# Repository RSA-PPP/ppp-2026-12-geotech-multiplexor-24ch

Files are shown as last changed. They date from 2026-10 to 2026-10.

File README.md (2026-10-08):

# ppp-2026-13-geotech-multiplexor-24ch

> **Red Sísmica del Austro (RSA) — Universidad de Cuenca**  
> Prácticas Preprofesionales (PPP) • Sistemas Embebidos, Instrumentación Geotécnica y Control Electromecánico

---

## 📋 Ficha Técnica del Proyecto

| Campo | Detalle |
| :--- | :--- |
| **Código Institucional** | `RSA-PPP-2026-13` |
| **Nombre del Proyecto** | Sistema de Adquisición Electromecánico Multiplexado para Galgas Extensométricas en Presas (ESP32 y PIC16F628A) |
| **Pasante** | Walter Calderón (`walter.calderon@ucuenca.edu.ec`) |
| **Carrera / Institución** | Ingeniería en Telecomunicaciones — Universidad de Cuenca |
| **Tutor Institucional** | Ing. Milton Muñoz (`milton.munozc@ucuenca.edu.ec`) — RSA |
| **Duración / Horas** | 144 horas (10.5 semanas) • Presencial |
| **Fecha de Ejecución** | 2026-10-01 al 2026-12-18 |
| **Estado** | `En Ejecución` |

---

## 🎯 Descripción General y Objetivos

La Red Sísmica del Austro (RSA) gestiona la auscultación estructural continua de presas hidroeléctricas críticas (como Chanlud y Labrado), donde la monitorización de la estabilidad del cuerpo de presa depende de redes de **galgas extensométricas de 4 hilos** embebidas en el concreto y galerías. Cada sensor entrega dos variables físicas acopladas: **deformación mecánica ($\mu\varepsilon$)** y **temperatura interna ($^\circ\text{C}$)** para compensación térmica.

Para optimizar costos de instrumental analógico de ultra alta resolución, el sistema utiliza un mecanismo de multiplexación electromecánica compuesto por **dos selectores rotativos mecánicos de 12 canales** (totalizando 24 sensores analógicos). Cada selector es gobernado por un motor DC acoplado a encoders ópticos de ranura y referencia absoluta (*Home*). La conmutación entre el modo de deformación y el modo de temperatura se realiza mediante un banco de relés (K1..K5) que reconfigura un puente de Wheatstone conectado al convertidor analógico-digital de 24 bits **HX711**.

Este proyecto implementa una arquitectura distribuida de firmware resiliente y de alta precisión:
* **Controlador Esclavo (Microchip PIC16F628A):** Firmware en C (XC8) para posicionamiento angular determinista por interrupciones, frenado dinámico activo en puente H L293D y parser binario UART a 9600 bps.
* **Nodo Maestro de Gestión (Espressif ESP32-WROOM-32):** Firmware en C++ (PlatformIO) para lectura del HX711, secuenciamiento de relés con tiempos muertos de guarda ($\ge 20\text{ ms}$), datalogger autónomo en MicroSD (FAT32/CSV), pantalla LCD alfanumérica y telemetría por comandos ASCII vía RS-232 (115200 bps).

### Objetivos Clave
1. **Hardware y Diagnóstico de Encoders:** Auditar en osciloscopio las señales digitales de los encoders de ranura y muesca Home, y caracterizar las formas de onda de conmutación del puente H L293D.
2. **Firmware de Posicionamiento (PIC16F628A):** Desarrollar en MPLAB X / XC8 las rutinas de búsqueda de origen (*Homing*), conteo de ranuras por interrupciones y frenado dinámico asistido para evitar deslizamientos por inercia.
3. **Protocolo Inter-Microcontroladores:** Diseñar el enlace serie UART binario robusto con delimitadores y suma de comprobación XOR a 9600 bps con máquina de reintentos y tolerancia a fallos.
4. **Adquisición HX711 y Reconfiguración de Puente:** Desarrollar el driver de lectura diferencial de 24 bits para el HX711 y el secuenciador de relés K1..K5 con tiempos de estabilización (*dead-time* $\ge 20\text{ ms}$).
5. **Datalogger MicroSD, Interfaz LCD y Telemetría RS-232:** Implementar la persistencia local en `DATALOG.CSV`, la pantalla informativa LCD y el protocolo de telemetría exterior compatible con sistemas SCADA.
6. **Barrido Secuencial de 24 Canales y Ensayo en Banco:** Orquestar el ciclo completo de auscultación ($\le 90\text{ s}$ para 24 canales) y evaluar la resiliencia en un ensayo de 100 barridos continuos con resistencias patrón.
7. **Guía de Troubleshooting y Documentación Final:** Redactar el manual de solución de averías electromecánicas e Informe Técnico Final.

> 📄 Para consultar el cronograma detallado semana a semana, la carga horaria y los checkpoints verificables, revisa el [Plan de Trabajo Oficial](docs/planificacion.md).

---

## 🏗️ Arquitectura del Sistema y Flujo de Trabajo

```text
+-----------------------------------------------------------------------------------+
|                        DIAGRAMA DE ARQUITECTURA DISTRIBUIDA                       |
+-----------------------------------------------------------------------------------+
|                                                                                   |
|  [24 Galgas Extensométricas en Presa]                                            |
|         |                                                                         |
|         v                                                                         |
|  [Selectores Rotativos Electromecánicos M1 y M2 (12 canales c/u)]                 |
|         ^                                                                         |
|         | (Acoplamiento Mecánico)                                                 |
|  [2x Motores DC con Encoders Ópticos (sens1 / sens2_Home)]                       |
|         ^                                                                         |
|         | (Driver H-Bridge L293D con Frenado Dinámico)                            |
|  [Microchip PIC16F628A - Esclavo de Motores]                                      |
|         ^                                                                         |
|         | (Enlace UART Binario @ 9600 bps / Checksum XOR)                         |
|         v                                                                         |
|  [Espressif ESP32 - Maestro de Adquisición y Gestión]                             |
|  ├── Secuenciador de Relés K1..K5 (Dead-time >= 20 ms) ---> [Puente Wheatstone]   |
|  ├── Driver ADC Diferencial 24-bit (HX711) <----------------+                     |
|  ├── Datalogger Autónomo MicroSD (Bus SPI / FAT32 / DATALOG.CSV)                  |
|  ├── Interfaz de Operación Local (Pantalla LCD Alfanumérica)                      |
|  └── Puerto Serie de Telemetría RS-232 / SCADA ASCII @ 115200 bps                 |
+-----------------------------------------------------------------------------------+
```

---

## 📂 Estructura del Repositorio

> [!IMPORTANT]
> **Estructura Raíz Inmutable:** Para mantener la coherencia con los lineamientos de la RSA, la estructura de carpetas raíz no debe ser alterada ni renombrada sin previa coordinación con el tutor.

```text
ppp-2026-13-geotech-multiplexor-24ch/
├── data/
│   ├── evidence/              # Capturas oscilográficas, evidencias de frenado y curvas
│   └── raw_samples/           # Volcados de prueba de tarjetas MicroSD (DATALOG.CSV)
│
├── docs/
│   ├── hardware/              # Esquemáticos de placas de relés, motores y pinouts
│   ├── troubleshooting/       # Bitácora de fallas mecánicas, atascos y calibración
│   └── planificacion.md       # Documento rector del plan de trabajo (144h) y checkpoints
│
├── firmware/
│   ├── common/                # Definiciones de tramas binarias UART y constantes globales
│   ├── drivers/               # Librerías de bajo nivel: HX711, LCD, L293D, MicroSD
│   ├── pic16f628a/            # Proyecto MPLAB X / XC8 para control de motores
│   ├── esp32/                 # Proyecto PlatformIO / C++ maestro de adquisición
│   └── tests/                 # Firmwares de verificación de reloj, relés y encoders
│
├── python/
│   ├── scripts/               # Scripts de monitoreo RS-232 y parser de DATALOG.CSV
│   ├── utils/                 # Utilitarios para cálculo de estadísticas y verificación
│   └── requirements.txt       # Dependencias de Python para herramientas de soporte PC
│
├── README.md                  # Este documento
└── .gitignore                 # Exclusiones de Git (MPLAB X, PlatformIO, Python, SO)
```

---

## 🛠️ Herramientas y Requisitos de Desarrollo

* **Hardware / Instrumental:**
  - Microcontroladores Microchip **PIC16F628A** y módulo Espressif **ESP32-WROOM-32**.
  - Programador Microchip **PICkit 3 / 4** o **SNAP** con interfaz ICSP.
  - Driver H-Bridge **L293D** y banco de relés conmutadores K1..K5.
  - ADC diferencial de 24 bits **HX711** y módulo MicroSD SPI.
  - Osciloscopio digital, analizador lógico de 8 canales y multímetro de banco.
  - Caja de décadas de resistencias patrón ($350\,\Omega$ y $120\,\Omega \pm 0.05\%$).
* **Entornos de Desarrollo e IDEs:**
  - **MPLAB X IDE v6.xx** con compilador **Microchip XC8** para el PIC16F628A.
  - **VS Code + PlatformIO** (o ESP-IDF / Arduino Core) para el ESP32.
* **Herramientas de Soporte PC:**
  - Python 3.10+ en entorno virtual (`.venv`):
    ```bash
    pip install -r python/requirements.txt
    ```

---

## 🚀 Puesta en Marcha

### 1. Clonar el Repositorio
```bash
git clone git@github.com-rsa:RSA-PPP/ppp-2026-13-geotech-multiplexor-24ch.git
cd ppp-2026-13-geotech-multiplexor-24ch
```

### 2. Compilación del Firmware del Esclavo (PIC16F628A)
1. Abrir **MPLAB X IDE**.
2. Abrir el proyecto ubicado en `firmware/pic16f628a/`.
3. Seleccionar el compilador **XC8** y la herramienta de programación (**PICkit 3/4**).
4. Compilar (`Clean and Build`) y programar la tarjeta de control de motores vía ICSP.

### 3. Compilación del Firmware del Maestro (ESP32)
1. Abrir **VS Code** con la extensión **PlatformIO**.
2. Abrir la carpeta `firmware/esp32/`.
3. Compilar el proyecto (`PlatformIO: Build`) y subir al módulo vía puerto serie (`PlatformIO: Upload`).

### 4. Herramientas de PC y Telemetría RS-232
```powershell
python -m venv .venv
.\.venv\Scripts\Activate.ps1
pip install -r python/requirements.txt
python python/scripts/scada_monitor.py
```

---

## 🛡️ Reglas de Trabajo y Control de Versiones

Para asegurar la calidad y trazabilidad del proyecto durante las prácticas:

1. **Rama Principal:** La rama activa de trabajo es **`main`**. Realiza commits frecuentes y atómicos al finalizar cada bloque o jornada de trabajo.
2. **Formato de Commits:** Utiliza la convención estándar en minúsculas:
   - `feat: [nueva funcionalidad, driver o máquina de estados implementada]`
   - `fix: [corrección de bug en firmware, protocolo o circuito]`
   - `docs: [actualización de esquemas, pinouts, troubleshooting o informe]`
   - `test: [pruebas de encoders, oscilogramas o calibración con resistencias patrón]`
   - `refactor: [optimización de temporizaciones sin cambio de comportamiento]`
3. **Integridad de Código:** No subas archivos temporales de compilación (`.o`, `.d`, carpetas `build/`, `.pio/`) ni volcados masivos sin comprimir. Apóyate en el archivo `.gitignore`.

---

## 📞 Contacto y Soporte Institucional

* **Tutor Institucional:** Ing. Milton Muñoz (`milton.munozc@ucuenca.edu.ec`)
* **Institución:** [Red Sísmica del Austro (RSA)](https://redsismicaaustro.github.io/RSA-Metodologias) — Universidad de Cuenca

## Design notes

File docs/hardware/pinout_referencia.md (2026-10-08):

# Mapeo de Pines y Señales de Referencia (Hardware Fabricado)

> **Red Sísmica del Austro (RSA) — Universidad de Cuenca**  
> Proyecto: `RSA-PPP-2026-13` • Multiplexor Geotécnico de 24 Canales  
> Documento de referencia técnica derivado de los esquemáticos KiCad y prototipos funcionales.

---

## 1. Nodo Maestro: Espressif ESP32-WROOM-32

Mapeo de señales implementado en la tarjeta adaptadora [`acople_esp32`](file:///C:/Users/miltonrsa/Documents/git/ppp/ppp-2026-13-geotech-multiplexor-24ch/docs/hardware/kicad/acople_esp32/) y validado en el prototipo [`legacy_micropython`](file:///C:/Users/miltonrsa/Documents/git/ppp/ppp-2026-13-geotech-multiplexor-24ch/firmware/esp32/legacy_micropython/):

### 1.1. Instrumentación Analógica (ADC 24-bit HX711)
| Pin ESP32 | Señal HX711 | Dirección | Descripción |
| :---: | :---: | :---: | :--- |
| **GPIO 4** | `DOUT` (DT) | Entrada | Línea serial de datos del HX711 (pulso bajo = dato listo) |
| **GPIO 33** | `PD_SCK` (SCK) | Salida | Reloj de lectura generado por el ESP32 (24 pulsos + 1 para Ganancia 128) |

> [!IMPORTANT]
> Mantener `PD_SCK` en nivel bajo durante reposo. Si permanece en nivel alto más de $60\,\mu\text{s}$, el HX711 entra en modo de bajo consumo (*Power Down*).

### 1.2. Banco de Conmutación de Relés (K1..K5)
Controla los transistores que conmutan la topología del puente de Wheatstone y la selección de modo:

| Pin ESP32 | Relé / Función | Estado Lógico | Acción Eléctrica |
| :---: | :---: | :---: | :--- |
| **GPIO 13** | Habilitación Medición | `0` = Deshabilitado<br>`1` = Habilitado | Conecta la salida del puente al convertidor HX711 |
| **GPIO 14** | Alimentación Puente | `0` = Desenergizado<br>`1` = Energizado (3.3V) | Aplica tensión de excitación al lazo del sensor |
| **GPIO 16** | Relé Selección Modo (Bit 0) | Conmuta rama | Junto con GPIO 17 define modo Deformación vs Temperatura |
| **GPIO 17** | Relé Selección Modo (Bit 1) | Conmuta rama | Ver tabla de verdad de modos |
| **GPIO 25** | Selección Tipo Sensor | `0` = Sensor Tipo 1<br>`1` = Sensor Tipo 2 | Adapta la resistencia puente según tecnología de galga |

#### Tabla de Verdad de Modos de Medición (GPIO 16 / 17):
| GPIO 17 | GPIO 16 | Modo Seleccionado | Estado |
| :---: | :---: | :--- | :--- |
| **0** | **0** | **Deformación Mecánica ($\mu\varepsilon$)** | Modo Nominal |
| `0` | `1` | Configuración Inválida 1 | Prohibido en software |
| `1` | `0` | Configuración Inválida 2 | Prohibido en software |
| **1** | **1** | **Temperatura Interna ($^\circ\text{C}$)** | Modo Nominal |

### 1.3. Bus SPI — Datalogger Tarjeta MicroSD
| Pin ESP32 | Señal MicroSD | Descripción |
| :---: | :---: | :--- |
| **GPIO 5** | `CS` (Chip Select) | Selección de esclavo SPI (activo en bajo) |
| **GPIO 23** | `MOSI` | Master Out Slave In |
| **GPIO 19** | `MISO` | Master In Slave Out |
| **GPIO 18** | `SCK` | Reloj de bus SPI |

### 1.4. Bus I2C — Pantalla LCD y RTC
| Pin ESP32 | Señal I2C | Dirección I2C | Dispositivo |
| :---: | :---: | :---: | :--- |
| **GPIO 21** | `SDA` | — | Línea de datos bidireccional |
| **GPIO 22** | `SCL` | — | Línea de reloj (100 kHz estándar) |
| *Bus I2C* | — | `0x27` o `0x3F` | Módulo PCF8574 (Pantalla LCD Alfanumérica 16x2 / 20x4) |
| *Bus I2C* | — | `0x68` | Módulo RTC de alta precisión DS3231 |

### 1.5. Interfaz Local y Actuadores Auxiliares
| Pin ESP32 | Función | Tipo | Descripción |
| :---: | :---: | :---: | :--- |
| **GPIO 15** | Touch SD | Entrada Capacitiva | Sensor táctil para desmontar/sincronizar MicroSD |
| **GPIO 2** | LED Neopixel | Salida Digital | LED direccionable WS2812B para diagnóstico de estado visual |

### 1.6. Enlace UART Inter-Microcontroladores (ESP32 $\leftrightarrow$ PIC16F628A)
* **Baudrate:** 9600 bps (8N1).
* **Puerto ESP32:** `UART2` (o configurado vía `HardwareSerial`).
* **Conexión cruzada:** TX ESP32 $\rightarrow$ RX PIC (RB1), RX ESP32 $\leftarrow$ TX PIC (RB2), GND común.

---

## 2. Controlador Esclavo: Microchip PIC16F628A

Mapeo extraído del esquemático [`control_motores`](file:///C:/Users/miltonrsa/Documents/git/ppp/ppp-2026-13-geotech-multiplexor-24ch/docs/hardware/kicad/control_motores/) y código base [`Control_motor.X`](file:///C:/Users/miltonrsa/Documents/git/ppp/ppp-2026-13-geotech-multiplexor-24ch/firmware/pic16f628a/Control_motor.X/):

### 2.1. Pines del Puerto B (PORTB)
| Pin PIC | Nombre Pin | Dirección | Función Asociada |
| :---: | :---: | :---: | :--- |
| **RB0** | `RB0/INT` | Entrada | Reservado / Interrupción externa de conteo |
| **RB1** | `RB1/RX` | Entrada | Receptor serie USART (9600 bps desde ESP32) |
| **RB2** | `RB2/TX` | Salida | Transmisor serie USART (9600 bps hacia ESP32) |
| **RB3** | `M2_EN` | Salida | Habilitación (*Enable*) Driver Puente H L293D para Motor 2 |
| **RB4** | `M1_EN` | Salida | Habilitación (*Enable*) Driver Puente H L293D para Motor 1 |
| **RB5** | `RB5` | I/O | Línea auxiliar / libre |
| **RB6** | `PGC` | Entrada | Reloj de programación ICSP (PICkit) |
| **RB7** | `PGD` | I/O | Datos de programación ICSP (PICkit) |

### 2.2. Pines del Puerto A (PORTA) — Encoders y Dirección de Motores
> [!NOTE]
> Para usar PORTA como I/O digitales, es mandatorio configurar `CMCON = 0x07` al iniciar el microcontrolador para apagar los comparadores analógicos internos.

* **Dirección de Motores en Puente H (L293D):**
  * `M1_1` y `M1_2`: Entradas de dirección para Motor 1.
  * `M2_1` y `M2_2`: Entradas de dirección para Motor 2.
  * **Frenado Dinámico Activo:** Conducir simultáneamente ambas entradas a nivel alto (`M1_1 = 1` y `M1_2 = 1`) durante 40 a 50 ms antes de apagar `M1_EN = 0`.
* **Sensores Ópticos de Posicionamiento:**
  * `SENS1_M1_1`: Encoder óptico de ranuras de paso para Motor 1 (conteo de canales 1..12).
  * `SENS2_M1_1`: Sensor óptico de muesca absoluta Home para Motor 1 (referencia canal 1).
  * `SENS1_M2_1`: Encoder óptico de ranuras de paso para Motor 2 (conteo de canales 13..24).
  * `SENS2_M2_1`: Sensor óptico de muesca absoluta Home para Motor 2 (referencia canal 13).

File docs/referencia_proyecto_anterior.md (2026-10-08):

# Guía de Referencia Técnica y Material Heredado
## Proyecto: Sistema de Adquisición Electromecánico Multiplexado para Galgas Extensométricas en Presas (ESP32 y PIC16F628A)

Este documento establece el puente técnico y metodológico entre los prototipos previos de hardware/firmware y la ejecución del plan de trabajo oficial (**`RSA-PPP-2026-13`**), desarrollado por **Walter Calderón** bajo la tutoría del **Ing. Milton Muñoz**.

---

## 📌 Datos de Identificación del Proyecto

| Parámetro | Detalle |
| :--- | :--- |
| **Código Institucional** | `RSA-PPP-2026-13` |
| **Proyecto** | Sistema de Adquisición Electromecánico Multiplexado para Galgas Extensométricas en Presas (ESP32 y PIC16F628A) |
| **Pasante** | Walter Calderón (`walter.calderon@ucuenca.edu.ec`) |
| **Tutor Institucional** | Ing. Milton Muñoz (`milton.munozc@ucuenca.edu.ec`) — Red Sísmica del Austro (RSA) |
| **Repositorio** | [RSA-PPP/ppp-2026-13-geotech-multiplexor-24ch](https://github.com/RSA-PPP/ppp-2026-13-geotech-multiplexor-24ch) |
| **Plan Rector** | [docs/planificacion.md](file:///C:/Users/miltonrsa/Documents/git/ppp/ppp-2026-13-geotech-multiplexor-24ch/docs/planificacion.md) (144 horas) |

---

## 🔍 Resumen del Material Heredado (Qué está disponible y probado)

Se ha transferido al repositorio todo el desarrollo previo clasificado y depurado para servir de base en las distintas fases del proyecto:

### 1. Diseños Circuitales y Archivos KiCad (`docs/hardware/kicad/`)
* **Placa de Acople ESP32 ([`docs/hardware/kicad/acople_esp32/`](file:///C:/Users/miltonrsa/Documents/git/ppp/ppp-2026-13-geotech-multiplexor-24ch/docs/hardware/kicad/acople_esp32/)):**  
  Diseño esquemático (`.kicad_sch`), ruteo de circuito impreso (`.kicad_pcb`), paquete de fabricación Gerber/BOM para JLCPCB y diagrama vectorial (`acople_sp32.svg`). Define la interfaz física entre el módulo ESP32-WROOM-32, el ADC HX711, la tarjeta MicroSD y los conectores a la placa de relés y motores.
* **Control de Motores PIC16F628A ([`docs/hardware/kicad/control_motores/`](file:///C:/Users/miltonrsa/Documents/git/ppp/ppp-2026-13-geotech-multiplexor-24ch/docs/hardware/kicad/control_motores/)):**  
  Esquemático del circuito que integra el microcontrolador PIC16F628A, el driver puente H L293D para los dos motores DC (M1 y M2) y las entradas de acondicionamiento para los sensores ópticos de ranura y *Home*.
* **Puente de Relés ([`docs/hardware/kicad/puente_reles/`](file:///C:/Users/miltonrsa/Documents/git/ppp/ppp-2026-13-geotech-multiplexor-24ch/docs/hardware/kicad/puente_reles/)):**  
  Diseño circuital del banco de relés (K1..K5) que conmuta la topología del puente de Wheatstone para alternar entre el canal de deformación mecánica ($\mu\varepsilon$) y el sensor de temperatura ($^\circ\text{C}$).
* **Acondicionamiento Legacy ([`docs/hardware/kicad/acondicionamiento_legacy/`](file:///C:/Users/miltonrsa/Documents/git/ppp/ppp-2026-13-geotech-multiplexor-24ch/docs/hardware/kicad/acondicionamiento_legacy/)):**  
  Esquemático histórico con amplificador de instrumentación INA114AP para consulta y referencia comparativa.

### 2. Planos CAD de Envolvente y Caja (`docs/hardware/cad/`)
* **Archivo Vectorworks ([`docs/hardware/cad/esquemas.vwx`](file:///C:/Users/miltonrsa/Documents/git/ppp/ppp-2026-13-geotech-multiplexor-24ch/docs/hardware/cad/esquemas.vwx)):**  
  Planos mecánicos y vistas de disposición física de la caja de medición donde van instalados los selectores rotativos electromecánicos y los soportes de motor.

### 3. Firmware Base del Controlador Esclavo (`firmware/pic16f628a/`)
* **Proyecto MPLAB X IDE ([`firmware/pic16f628a/Control_motor.X/`](file:///C:/Users/miltonrsa/Documents/git/ppp/ppp-2026-13-geotech-multiplexor-24ch/firmware/pic16f628a/Control_motor.X/)):**  
  Proyecto base compilable en XC8 con:
  * Configuración de *fuses* (`#pragma config`) y oscilador interno a 4 MHz (`INTOSCIO`).
  * Desactivación de comparadores analógicos (`CMCON = 0x07`) para liberar PORTA.
  * Inicialización de USART a 9600 bps (`TXSTA`, `RCSTA`, `SPBRG = 25`).
  * Archivo fuente [`newmain.c`](file:///C:/Users/miltonrsa/Documents/git/ppp/ppp-2026-13-geotech-multiplexor-24ch/firmware/pic16f628a/Control_motor.X/newmain.c) con parser básico de prueba (`PING`, `A1`, `R1`, etc.).

### 4. Firmware Prototipo del ESP32 en MicroPython (`firmware/esp32/legacy_micropython/`)
* **Golden Reference Funcional:**  
  Conjunto completo de scripts en MicroPython que sirvió para validar el hardware en laboratorio:
  * [`drivers/control_reles.py`](file:///C:/Users/miltonrsa/Documents/git/ppp/ppp-2026-13-geotech-multiplexor-24ch/firmware/esp32/legacy_micropython/drivers/control_reles.py): Abstracción orientada a objetos que contiene la **tabla de verdad exacta de los relés K1..K5** y los pines GPIO asignados.
  * [`drivers/hx711.py`](file:///C:/Users/miltonrsa/Documents/git/ppp/ppp-2026-13-geotech-multiplexor-24ch/firmware/esp32/legacy_micropython/drivers/hx711.py): Driver de lectura bit-banging de 24 bits para el HX711, tara y promedio.
  * [`drivers/sd_spi.py`](file:///C:/Users/miltonrsa/Documents/git/ppp/ppp-2026-13-geotech-multiplexor-24ch/firmware/esp32/legacy_micropython/drivers/sd_spi.py): Inicialización del bus SPI para la tarjeta MicroSD.
  * [`drivers/lcd_i2c.py`](file:///C:/Users/miltonrsa/Documents/git/ppp/ppp-2026-13-geotech-multiplexor-24ch/firmware/esp32/legacy_micropython/drivers/lcd_i2c.py) e [`i2c_bus.py`](file:///C:/Users/miltonrsa/Documents/git/ppp/ppp-2026-13-geotech-multiplexor-24ch/firmware/esp32/legacy_micropython/drivers/i2c_bus.py): Manejo del bus I2C y display LCD 16x2.
  * [`drivers/touch_sd.py`](file:///C:/Users/miltonrsa/Documents/git/ppp/ppp-2026-13-geotech-multiplexor-24ch/firmware/esp32/legacy_micropython/drivers/touch_sd.py), [`ds3231.py`](file:///C:/Users/miltonrsa/Documents/git/ppp/ppp-2026-13-geotech-multiplexor-24ch/firmware/esp32/legacy_micropython/drivers/ds3231.py) y [`rgb_led.py`](file:///C:/Users/miltonrsa/Documents/git/ppp/ppp-2026-13-geotech-multiplexor-24ch/firmware/esp32/legacy_micropython/drivers/rgb_led.py): Controladores para periféricos auxiliares.
  * [`main.py`](file:///C:/Users/miltonrsa/Documents/git/ppp/ppp-2026-13-geotech-multiplexor-24ch/firmware/esp32/legacy_micropython/main.py): Lógica de adquisición secuencial, descarte de primeras lecturas y cálculo de milivoltios.

### 5. Scripts de Soporte en PC (`python/scripts/legacy_pc/`)
* Scripts auxiliares ([`enviar_esp32.py`](file:///C:/Users/miltonrsa/Documents/git/ppp/ppp-2026-13-geotech-multiplexor-24ch/python/scripts/legacy_pc/enviar_esp32.py) y [`config.py`](file:///C:/Users/miltonrsa/Documents/git/ppp/ppp-2026-13-geotech-multiplexor-24ch/python/scripts/legacy_pc/config.py)) empleados para comunicación por puerto serie y carga de archivos hacia el microcontrolador.

---

## ⚠️ Cuellos de Botella y Limitaciones Heredadas (¡Lectura Obligatoria!)

El material previo representa una base experimental de gran valor, pero **no constituye la solución de ingeniería final**. Presenta limitaciones técnicas críticas que debes resolver a lo largo de tu pasantía:

### 1. En el Controlador de Motores (PIC16F628A)
* **Falta de Frenado Dinámico Activo:**  
  El código anterior (`newmain.c`) solo apagaba las salidas al detener la marcha. Debido a la inercia del rotor de los motores DC acoplados a la reducción mecánica, el disco selector se pasaba de largo (*overshoot*), dejando los contactos del selector desalineados.  
  👉 **Tu reto (Fase 2):** Implementar frenado dinámico activo en el puente H L293D conmutando las dos entradas a nivel alto simultáneamente (`IN1=1, IN2=1`) durante una ventana calibrada (40–50 ms) antes de cortar `ENABLE=0`.
* **Vulnerabilidad a Rebotes y Pérdida de Pasos:**  
  La lectura previa de los encoders ópticos se hacía por sondeo simple en bucle, vulnerable a vibraciones mecánicas y ruidos.  
  👉 **Tu reto (Fase 2):** Implementar la búsqueda de origen absoluta (*Homing* en `sens2`) y conteo determinista de ranuras (`sens1`) asistido por interrupciones y temporizadores de guarda (*timeout* de 5 segundos para detectar atascos).
* **Protocolo Serie Informal (Texto Plano):**  
  El PIC procesaba comandos de texto ASCII sin delimitadores estrictos ni verificación de integridad (e.g. `"A1"` o `"R1"`).  
  👉 **Tu reto (Fase 3):** Sustituir este esquema por el **protocolo binario estructurado con delimitadores `0xAA` / `0x55` y suma de comprobación XOR** estipulado en la planificación.

### 2. En el Nodo Maestro (ESP32)
* **Migración Obligatoria de MicroPython a C++ (PlatformIO):**  
  El código heredado está escrito en MicroPython. Si bien sirvió como prototipo rápido, MicroPython introduce latencias variables (*jitter* del recolector de basura) que impiden garantizar el estricto sincronismo en microsegundos que exige el tren de pulsos del HX711 y la orquestación en tiempo real.  
  👉 **Tu reto (Fase 4):** Portar y refactorizar la lógica hacia **C++ nativo en PlatformIO**, beneficiándote de la velocidad, concurrencia de tareas FreeRTOS y tipado estricto.
* **Transitorios por Falta de Tiempos Muertos (*Dead-Time*):**  
  En las pruebas previas, el accionamiento de relés no contemplaba retardos de guarda de estabilización de contactos mecánicos (*settling time*), inyectando ruido eléctrico severo a las primeras conversiones de 24 bits del ADC.  
  👉 **Tu reto (Fase 4):** Programar un secuenciador con tiempos muertos de guarda $\ge 20\text{ ms}$ y descarte de las dos primeras muestras post-conmutación.
* **Persistencia y Telemetría Industriales Incompletas:**  
  El prototipo anterior solo imprimía valores por la consola serial de depuración.  
  👉 **Tu reto (Fase 5 y 6):** Desarrollar el datalogger autónomo en MicroSD con archivos CSV estructurados (`DATALOG.CSV`), la interfaz LCD interactiva y el protocolo exterior RS-232 / SCADA a 115200 bps.

---

## 🗺️ Mapa de Navegación del Material Proporcionado

Todo el material útil ha sido ubicado en el árbol del repositorio:

| Ruta en el Repositorio | Contenido | Propósito y Uso Recomendado |
| :--- | :--- | :--- |
| [`docs/hardware/pinout_referencia.md`](file:///C:/Users/miltonrsa/Documents/git/ppp/ppp-2026-13-geotech-multiplexor-24ch/docs/hardware/pinout_referencia.md) | Tabla consolidada de señales y pines | **Consulta inmediata:** Consulta rápida de GPIOs de ESP32, pines de PIC y tabla de verdad de relés. |
| [`docs/hardware/kicad/acople_esp32/`](file:///C:/Users/miltonrsa/Documents/git/ppp/ppp-2026-13-geotech-multiplexor-24ch/docs/hardware/kicad/acople_esp32/) | Proyecto KiCad de placa ESP32 y Gerbers | **Auditoría física (Fase 1 y 4):** Verificar continuidades, niveles de tensión y ruteo hacia el HX711 y MicroSD. |
| [`docs/hardware/kicad/control_motores/`](file:///C:/Users/miltonrsa/Documents/git/ppp/ppp-2026-13-geotech-multiplexor-24ch/docs/hardware/kicad/control_motores/) | Proyecto KiCad del controlador PIC16F628A | **Hardware de potencia (Fase 1 y 2):** Conexiones del L293D, pines de encoders y puerto serie. |
| [`docs/hardware/kicad/puente_reles/`](file:///C:/Users/miltonrsa/Documents/git/ppp/ppp-2026-13-geotech-multiplexor-24ch/docs/hardware/kicad/puente_reles/) | Proyecto KiCad del banco K1..K5 | **Topología de galgas (Fase 1 y 4):** Rastreo de las ramas del puente de Wheatstone y contactos de relés. |
| [`docs/hardware/cad/esquemas.vwx`](file:///C:/Users/miltonrsa/Documents/git/ppp/ppp-2026-13-geotech-multiplexor-24ch/docs/hardware/cad/esquemas.vwx) | Planos mecánicos en Vectorworks | **Ensamble mecánico:** Inspeccionar dimensiones mecánicas y sujeción de motores y selectores. |
| [`firmware/pic16f628a/Control_motor.X/`](file:///C:/Users/miltonrsa/Documents/git/ppp/ppp-2026-13-geotech-multiplexor-24ch/firmware/pic16f628a/Control_motor.X/) | Proyecto MPLAB X / XC8 (`newmain.c`) | **Código base de partida (Fase 1, 2 y 3):** Base para implementar Homing, frenado dinámico y protocolo binario UART. |
| [`firmware/esp32/legacy_micropython/`](file:///C:/Users/miltonrsa/Documents/git/ppp/ppp-2026-13-geotech-multiplexor-24ch/firmware/esp32/legacy_micropython/) | Scripts funcionales en MicroPython | **Golden Reference algorítmica (Fase 4):** Consulta de lógica de relés, timing de HX711 y conversión a milivoltios para portar a C++. |
| [`python/scripts/legacy_pc/`](file:///C:/Users/miltonrsa/Documents/git/ppp/ppp-2026-13-geotech-multiplexor-24ch/python/scripts/legacy_pc/) | Herramientas seriales para PC | **Pruebas de enlace:** Referencia para estructurar el cliente SCADA en Python. |

---

## 🚀 Guía de Aprovechamiento Paso a Paso según el Plan de Trabajo (144h)

### Semana 1: Fase 1 — Diagnóstico de Hardware y Encoders del PIC16F628A
1. Abre los esquemáticos KiCad en [`docs/hardware/kicad/control_motores/`](file:///C:/Users/miltonrsa/Documents/git/ppp/ppp-2026-13-geotech-multiplexor-24ch/docs/hardware/kicad/control_motores/) y [`acople_esp32/`](file:///C:/Users/miltonrsa/Documents/git/ppp/ppp-2026-13-geotech-multiplexor-24ch/docs/hardware/kicad/acople_esp32/).
2. Revisa la tabla rápida en [`docs/hardware/pinout_referencia.md`](file:///C:/Users/miltonrsa/Documents/git/ppp/ppp-2026-13-geotech-multiplexor-24ch/docs/hardware/pinout_referencia.md) para cotejar alimentaciones de 5V y 3.3V.
3. Abre el proyecto [`firmware/pic16f628a/Control_motor.X/`](file:///C:/Users/miltonrsa/Documents/git/ppp/ppp-2026-13-geotech-multiplexor-24ch/firmware/pic16f628a/Control_motor.X/) en MPLAB X, compila con XC8 y programa el PIC mediante PICkit / ICSP.
4. Conecta el osciloscopio en las señales `SENS1` y `SENS2` de ambos ejes, gira manualmente los discos y verifica niveles TTL limpios sin ruido ni rebotes (**Checkpoint 1.2**).

### Semanas 2–3: Fase 2 — Firmware PIC: Homing, Ranuras y Frenado Dinámico
1. Toma el bucle principal de [`newmain.c`](file:///C:/Users/miltonrsa/Documents/git/ppp/ppp-2026-13-geotech-multiplexor-24ch/firmware/pic16f628a/Control_motor.X/newmain.c) y reemplázalo por una máquina de estados formal (`ESTADO_HOMING`, `ESTADO_MOVIENDO`, `ESTADO_FRENADO`, `ESTADO_LISTO`, `ESTADO_ERROR`).
2. Implementa la rutina de búsqueda de *Home*: giro controlado hasta flanco en `sens2` y reinicio del contador a `pos = 1` (**Checkpoint 2.1**).
3. Implementa el **frenado dinámico**: al detectar la ranura de destino en `sens1`, activa `IN1=1, IN2=1` durante 45 ms antes de apagar `ENABLE=0`. Captura con osciloscopio para verificar la ausencia de sobreimpulso (**Checkpoint 2.2**).
4. Ejecuta 50 ciclos continuos de selección aleatoria de canal validando alineación mecánica (**Checkpoint 2.3**).

### Semana 4: Fase 3 — Protocolo Binario UART (ESP32 $\leftrightarrow$ PIC16F628A)
1. Sustituye las cadenas de texto (`A1`, `R1`) de `newmain.c` por el parser de tramas binarias:
   $$[\text{HEADER: } 0\text{xAA}]\,[\text{MOTOR\_ID}]\,[\text{CMD}]\,[\text{PARAM}]\,[\text{CHECKSUM}]\,[\text{TAIL: } 0\text{x55}]$$
2. Programa la respuesta determinista del PIC con estados (`READY`, `MOVING`, `HOMING`, `ERROR`).
3. Diseña el cliente UART en C++ para el ESP32 con reintentos automáticos y recuperación ante desconexión (**Checkpoints 3.1, 3.2, 3.3**).

### Semanas 5–6: Fase 4 — Driver HX711 en C++ y Secuenciador de Relés K1..K5
1. Estudia [`legacy_micropython/drivers/control_reles.py`](file:///C:/Users/miltonrsa/Documents/git/ppp/ppp-2026-13-geotech-multiplexor-24ch/firmware/esp32/legacy_micropython/drivers/control_reles.py) para entender la conmutación de GPIO 13, 14, 16, 17 y 25.
2. Crea el proyecto C++ en PlatformIO bajo `firmware/esp32/`.
3. Desarrolla el driver C++ del HX711 basado en [`legacy_micropython/drivers/hx711.py`](file:///C:/Users/miltonrsa/Documents/git/ppp/ppp-2026-13-geotech-multiplexor-24ch/firmware/esp32/legacy_micropython/drivers/hx711.py), implementando el filtrado por mediana móvil y los tiempos de estabilización (*dead-time* $\ge 20\text{ ms}$).
4. Calibra con la caja de décadas de resistencias patrón ($350\,\Omega$ y $120\,\Omega$) verificando $R^2 \ge 0.999$ (**Checkpoints 4.1, 4.2, 4.3**).

### Semanas 7–8: Fase 5 — Datalogger MicroSD, Interfaz LCD y Telemetría RS-232
1. Configura el bus SPI en el ESP32 (GPIO 5, 18, 19, 23) usando `SD.h` o `SdFat`.
2. Implementa la persistencia en `DATALOG.CSV` con volcado forzado (`flush()`) tras cada lectura (**Checkpoint 5.1**).
3. Integra la pantalla LCD por I2C (GPIO 21 y 22) tomando como referencia [`legacy_micropython/drivers/lcd_i2c.py`](file:///C:/Users/miltonrsa/Documents/git/ppp/ppp-2026-13-geotech-multiplexor-24ch/firmware/esp32/legacy_micropython/drivers/lcd_i2c.py) (**Checkpoint 5.2**).
4. Implementa el parser de comandos ASCII por el puerto RS-232 (`READ:CH`, `SCAN:ALL`, `CAL:ZERO`, `LOG:STATUS`) (**Checkpoint 5.3**).

### Semanas 9–10: Fase 6 — Barrido Secuencial de 24 Canales y Tolerancia a Fallos
1. Integra la máquina de estados global: M1 (canales 1..12) y M2 (canales 13..24).
2. Optimiza los tiempos de ciclo para completar los 24 canales en menos de 90 segundos (**Checkpoint 6.1**).
3. Simula desconexión y atascos mecánicos forzados, validando que el sistema reporte `ERROR_M_STALL` en el CSV y prosiga con los siguientes canales sin colgarse (**Checkpoint 6.3**).
4. Corre el ensayo de estrés continuo de 100 barridos (2400 mediciones) (**Checkpoint 6.2**).

### Semanas 10–11: Fase 7 — Troubleshooting e Informe Final
1. Documenta las holguras mecánicas y el procedimiento de calibración de optoacopladores en `docs/troubleshooting/`.
2. Redacta el Informe Técnico Final institucional y prepara el repositorio para cierre y firma de actas (**Checkpoints 7.1, 7.2, 7.3**).

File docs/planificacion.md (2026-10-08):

---
titulo: "Plan de Trabajo de Prácticas Preprofesionales: Sistema de Adquisición Electromecánico Multiplexado de 24 Canales para Auscultación de Presas (ESP32 y PIC16F628A)"
proyecto: "Sistema de Adquisición Electromecánico Multiplexado para Galgas Extensométricas en Presas (ESP32 y PIC16F628A)"
codigo_proyecto: "RSA-PPP-2026-13"
area_tematica: "Sistemas Embebidos, Instrumentación Geotécnica, Control Electromecánico, Firmware Distribuido (UART/SPI) y Metrología de Galgas"
estado: "En Ejecución"
version: "1.0"
fecha_creacion: "2026-09-28"
fecha_actualizacion: "2026-09-28"

practicante:
  nombre: "Walter Calderón"
  cedula: "N/D"
  correo: "walter.calderon@ucuenca.edu.ec"
  carrera: "Ingeniería en Telecomunicaciones"
  institucion: "Universidad de Cuenca"

tutoria:
  tutor_institucional: "Ing. Milton Muñoz (Red Sísmica del Austro - RSA)"
  correo_tutor_institucional: "milton.munozc@ucuenca.edu.ec"

cronograma:
  duracion_total_horas: 144
  dedicacion_semanal_horas: 14
  duracion_semanas: 10.5
  fecha_inicio: "2026-10-01"
  fecha_fin_estimada: "2026-12-18"
  modalidad: "Presencial"

tecnologias:
  - "Microcontroladores y Arquitectura: Microchip PIC16F628A (controlador esclavo de motores) y Espressif ESP32-WROOM-32 (nodo maestro de adquisición y gestión)"
  - "Entornos de Desarrollo e IDEs: Microchip MPLAB X IDE + Compilador XC8 (PIC), VS Code + PlatformIO / ESP-IDF / Arduino Core (ESP32)"
  - "Adquisición y Acondicionamiento Analógico: ADC diferencial de 24 bits HX711 (Canal A, Ganancia 128), Banco de relés K1..K5 para reconfiguración del Puente de Wheatstone"
  - "Etapa de Potencia y Actuación: Driver de potencia H-Bridge L293D con frenado dinámico, 2 motores DC acoplados a selectores rotativos electromecánicos de 12 posiciones"
  - "Sensores de Posicionamiento: Encoders ópticos infrarrojos de ranuras (sens1_M1, sens1_M2) y muesca absoluta de referencia Home (sens2_M1, sens2_M2)"
  - "Protocolos y Comunicaciones: Bus UART serie binario robusto con delimitadores y checksum XOR (ESP32-PIC a 9600 bps), Enlace externo RS-232 / SCADA ASCII (115200 bps)"
  - "Almacenamiento Local y UI: Interfaz de bus SPI para tarjeta MicroSD (sistema de archivos FAT32, archivo DATALOG.CSV) y pantalla LCD alfanumérica"
  - "Instrumental de Laboratorio: Osciloscopio digital de fósforo, analizador lógico de 8 canales, multímetro de banco de alta precisión y simulador/resistencias patrón de galgas (350 Ω / 120 Ω)"

repositorio:
  url: "https://github.com/RSA-PPP/ppp-2026-13-geotech-multiplexor-24ch"
  rama_base: "main"

topics:
  - rsa-ppp
  - ucuenca
  - dam-monitoring
  - strain-gauges
  - esp32
  - pic-microcontroller
  - uart
  - spi
  - microsd
  - c
---

---

## 1. Antecedentes y Justificación Técnica

### 1.1. Contexto del Sistema y Estado Inicial del Artefacto
La Red Sísmica del Austro (RSA) gestiona la auscultación estructural de presas hidroeléctricas críticas (como Chanlud y Labrado), donde la monitorización de la estabilidad estática del cuerpo de presa depende de redes de **galgas extensométricas de 4 hilos** embebidas en el concreto y en galerías de drenaje. Cada transductor entrega dos variables físicas acopladas fundamentales: la **deformación mecánica ($\mu\varepsilon$)** y la **temperatura interna ($^\circ\text{C}$)** requerida para la compensación de deriva térmica del material.

Para economizar infraestructura de acondicionamiento de ultra alta resolución, el sistema de auscultación emplea un mecanismo de multiplexación electromecánica compuesto por dos selectores rotativos mecánicos de 12 canales cada uno (totalizando 24 sensores analógicos). Cada selector es impulsado por un motor de corriente continua acoplado a encoders ópticos de conteo de paso y detección de posición de inicio (*Home*). La conmutación entre el modo de lectura de deformación (lazo activo del transductor) y el modo de temperatura (resistencia compensadora) se realiza mediante un banco de relés miniatura (K1..K5) que reconfigura un puente de Wheatstone conectado a un convertidor analógico-digital (ADC) de 24 bits **HX711**.

En iteraciones preliminares del proyecto, el hardware de la placa base de motores (con microcontrolador Microchip PIC16F628A y puente H L293D) y la tarjeta adaptadora del nodo maestro (ESP32) fueron diseñadas y montadas en laboratorio, pero carecen de un firmware determinista, robusto y sincronizado que garantice mediciones fiables sin desalineaciones mecánicas ni derivas de muestreo.

### 1.2. Limitaciones Críticas o Cuellos de Botella Identificados
* **Desalineación Mecánica y Falta de Frenado Dinámico:** Debido a la inercia de los motores DC, al apagar el puente L293D el rotor continuaba girando por inercia, provocando que los contactos electromecánicos del selector quedaran a medio paso o en falso contacto. Se requiere la implementación estricta de frenado dinámico activo (`IN1=1, IN2=1`) controlado por software.
* **Vulnerabilidad a Ruidos y Desincronización en Encoders:** La lectura directa de los sensores ópticos de ranura presentaba disparos erráticos ante rebotes o vibraciones del motor, provocando que el conteo de posiciones se desfasara del canal real sin un mecanismo periódico de autocorrección o referenciación (*Homing*).
* **Transitorios Eléctricos por Conmutación de Relés:** El accionamiento simultáneo de los relés K1..K5 sin tiempos muertos (*dead-time*) ni retardos de estabilización de contactos (*settling time*) acoplaba transitorios severos a la entrada analógica del HX711, falseando las primeras conversiones de 24 bits.
* **Carencia de un Protocolo Binario Resiliente entre ESP32 y PIC:** La comunicación inter-microcontroladores carecía de sincronismo de trama y validación de integridad (checksum), provocando bloqueos permanentes del sistema maestro si el PIC no alcanzaba la posición en el tiempo previsto.
* **Dispersión de Datos sin Almacenamiento Seguro ni Interfaz de Campo:** Las lecturas se transmitían de forma cruda por consola serial sin respaldo local determinista en tarjeta MicroSD (FAT32/CSV) ni retroalimentación visual inmediata en pantalla LCD para los técnicos de presa.

### 1.3. Desacoplamiento del Alcance y Propuesta de Solución
La presente pasantía de **144 horas** aborda de manera integral el desarrollo, depuración, sincronización e integración del firmware distribuido para los microcontroladores PIC16F628A y ESP32, asegurando la validación en banco de los 24 canales de auscultación:
1. **Firmware del Esclavo PIC16F628A:** Desarrollo en MPLAB X / XC8 de las rutinas de posicionamiento absoluto (Homing), conteo determinista de ranuras por interrupciones, frenado dinámico asistido y parser de comandos binarios a 9600 bps.
2. **Firmware del Maestro ESP32:** Desarrollo en PlatformIO / C++ del controlador de bajo nivel para el ADC HX711, secuenciador con tiempos muertos de los relés K1..K5, datalogger en MicroSD con archivos CSV fechados, visualizador LCD y protocolo de telemetría exterior RS-232 / SCADA.
3. **Validación Experimental en Banco:** Caracterización con resistencias patrón de $350\,\Omega$ y $120\,\Omega$, medición de tiempos de ciclo de barrido ($\le 90\text{ s}$ para 24 canales) y verificación de repetibilidad estadística ($\sigma < 5\text{ LSB}$).

---

## 2. Objetivos del Plan de Trabajo

### 2.1. Objetivo General
Desarrollar, sincronizar y validar experimentalmente la arquitectura distribuida de firmware para el sistema de adquisición electromecánico multiplexado de 24 canales de galgas extensométricas de presas, integrando el control de motores y posicionamiento óptico en un PIC16F628A con la instrumentación diferencial de 24 bits (HX711), secuenciamiento de relés, almacenamiento en MicroSD y telemetría RS-232 en un ESP32, con el propósito de garantizar mediciones repetibles, continuas y con precisión submilimétrica en la auscultación estructural de la RSA.

### 2.2. Objetivos Específicos
1. **Hardware y Diagnóstico de Encoders:** Adecuar el banco de pruebas físico, auditar las señales de los encoders ópticos de ranura y de referencia absoluta (*Home*), y caracterizar las formas de onda de conmutación del puente H L293D con instrumental de laboratorio.
2. **Firmware de Posicionamiento (PIC16F628A):** Desarrollar e implementar en lenguaje C (XC8) las máquinas de estado para búsqueda de cero absoluto (*Homing*), desplazamiento determinista por conteo de ranuras de los 2 motores DC y frenado dinámico de inercia.
3. **Protocolo de Enlace Inter-Microcontroladores:** Diseñar e implementar el protocolo binario estructurado con tramas delimitadas y suma de comprobación XOR a través del canal UART serie entre el ESP32 y el PIC16F628A, garantizando tolerancia a fallos y reporte de atascos mecánicos.
4. **Adquisición de Alta Resolución y Reconfiguración de Puente:** Desarrollar en el ESP32 el controlador de lectura diferencial del HX711 y el secuenciador de relés K1..K5 con tiempos de estabilización (*dead-time* $\ge 20\text{ ms}$) para alternar de forma transparente entre la medición de deformación mecánica y la resistencia térmica interna.
5. **Datalogger, Telemetría y Validación Integral:** Integrar el almacenamiento autónomo en tarjeta MicroSD en formato CSV, la interfaz en pantalla LCD, el protocolo de comandos ASCII por RS-232, y ejecutar un ensayo de validación continua de 24 canales sobre un simulador patrón de galgas.

---

## 3. Plan de Trabajo Detallado y Checkpoints Cuantificables

### Fase 1: Diagnóstico de Hardware, Acondicionamiento de Banco y Encoders del PIC16F628A
* **Duración:** 15 horas (Semana 1)
* **Objetivo:** Verificar la integridad eléctrica de la tarjeta de control de motores, caracterizar los sensores ópticos de ambos ejes y configurar el entorno de compilación e in-circuit debugging.
* **Actividades técnicas:**
  1. Configuración del proyecto base en MPLAB X IDE v6.xx con el compilador Microchip XC8 en modo libre y enlace con programador PICkit 3/4 o SNAP en puerto ICSP.
  2. Verificación de continuidades, tensiones de alimentación (5V regulados para lógica y potencia de motores) y comprobación del registro `CMCON = 0x07` para liberar los pines analógicos del PORTA como entradas digitales.
  3. Caracterización con osciloscopio de las señales digitales de los encoders de ranura (`sens1_M1`, `sens1_M2`) y de referencia Home (`sens2_M1`, `sens2_M2`), evaluando niveles lógicos ($V_{OL}, V_{OH}$) y tiempos de subida/bajada.
  4. Inspección de las salidas de potencia del driver L293D hacia los motores DC M1 y M2, evaluando caídas de tensión y corriente en carga.
* **Checkpoints medibles para revisión:**
  - [ ] **CP 1.1:** Entorno de desarrollo MPLAB X y XC8 plenamente operativo; tarjeta del PIC reconocida y programada con firmware de prueba de parpadeo y verificación de reloj.
  - [ ] **CP 1.2:** Capturas oscilográficas registradas de los 4 sensores ópticos validando que no existen falsos disparos ni rebotes al girar manualmente los discos selectores.
  - [ ] **CP 1.3:** Tabla de tensiones y consumos de corriente en reposo y en movimiento de ambos motores documentada en la bitácora técnica.

---

### Fase 2: Firmware del Esclavo PIC16F628A: Homing, Conteo de Ranuras y Frenado Dinámico
* **Duración:** 30 horas (Semanas 2–3)
* **Objetivo:** Desarrollar el firmware de control de movimiento determinista para posicionar los selectores rotativos en cualquiera de sus 12 posiciones con alineación perfecta y sin deslizamiento por inercia.
* **Actividades técnicas:**
  1. Implementación de la rutina de búsqueda de referencia absoluta (*Homing*): giro a baja velocidad hasta detectar el flanco de subida en el sensor de muesca Home (`sens2`), detención inmediata y asignación de la variable `posicion_actual = 1`.
  2. Implementación de la subrutina de conteo de posiciones mediante interrupción por cambio de estado o sondeo determinista sobre `sens1`, actualizando el registro de paso en cada ranura detectada.
  3. Diseño de la rutina de frenado dinámico activo en el L293D: conmutación de las entradas de dirección a estado alto simultáneo (`IN1=1, IN2=1`) durante una ventana calibrada de 40 a 50 ms antes del apagado total (`ENABLE=0`).
  4. Implementación de temporizadores de guarda (*watchdog / timeout* de 5 segundos) para abortar la marcha y declarar condición de atasco mecánico si no se detectan pulsos de encoder.
  5. Ensayos de repetibilidad de 50 ciclos continuos de posicionamiento aleatorio (posiciones 1 a 12) evaluando desalineaciones angulares con microscopio o marcas visuales.
* **Checkpoints medibles para revisión:**
  - [ ] **CP 2.1:** Secuencia de *Homing* ejecutada con éxito en 10 intentos consecutivos en ambos motores (M1 y M2), restableciendo la posición de origen de forma exacta.
  - [ ] **CP 2.2:** Frenado dinámico operativo; el disco selector se detiene exactamente en el centro de la muesca de contacto sin sobreimpulso (*overshoot*).
  - [ ] **CP 2.3:** Prueba de estrés de 50 ciclos continuos de selección de canales sin un solo error de conteo ni desalineación de los contactos rotativos.

---

### Fase 3: Protocolo Binario Robusto UART y Enlace Maestro-Esclavo (ESP32 $\leftrightarrow$ PIC16F628A)
* **Duración:** 15 horas (Semana 4)
* **Objetivo:** Establecer una capa de comunicación serie determinista, binaria y tolerante a fallos entre el nodo maestro ESP32 y el controlador esclavo PIC16F628A.
* **Actividades técnicas:**
  1. Configuración del periférico USART del PIC16F628A a 9600 bps, 8 bits de datos, sin paridad y 1 bit de parada (8N1), gestionado por interrupción de recepción (RCIF).
  2. Implementación del parser receptor de comandos binarios con formato:
     $$\text{Trama Comandos: } [\text{HEADER: } 0\text{xAA}]\,[\text{MOTOR\_ID: } 1|2]\,[\text{CMD}]\,[\text{PARAM}]\,[\text{CHECKSUM}]\,[\text{TAIL: } 0\text{x55}]$$
     donde $\text{CHECKSUM} = \text{XOR}(\text{MOTOR\_ID}, \text{CMD}, \text{PARAM})$.
  3. Implementación del generador de tramas de respuesta del PIC:
     $$\text{Trama Respuesta: } [\text{HEADER: } 0\text{xBB}]\,[\text{MOTOR\_ID: } 1|2]\,[\text{STATUS}]\,[\text{POS\_ACTUAL}]\,[\text{CHECKSUM}]\,[\text{TAIL: } 0\text{x55}]$$
     con codificación de estados `READY (0x00)`, `MOVING (0x01)`, `HOMING (0x02)` y `ERROR (0xEE)`.
  4. Desarrollo del cliente de comunicación en el ESP32 (utilizando `HardwareSerial` UART2), implementando máquina de estados con reintentos automáticos (máximo 3) y descarte de bytes huérfanos.
  5. Pruebas de inyección de ruido y corte de línea para verificar la recuperación autónoma del enlace sin reinicio de los microcontroladores.
* **Checkpoints medibles para revisión:**
  - [ ] **CP 3.1:** Comunicación bidireccional estable a 9600 bps confirmada con analizador lógico; 100% de tramas válidas reconocidas por el parser.
  - [ ] **CP 3.2:** Detección y descarte comprobado de tramas corruptas mediante la verificación del checksum XOR.
  - [ ] **CP 3.3:** El ESP32 recibe correctamente el estado `READY` tras cada desplazamiento ordenado y detecta el código `ERROR (0xEE)` ante atascos forzados.

---

### Fase 4: Acondicionamiento Analógico en ESP32: Driver HX711 y Secuenciamiento de Relés K1..K5
* **Duración:** 30 horas (Semanas 5–6)
* **Objetivo:** Adquirir los desbalances de puente de Wheatstone con resolución de 24 bits y secuenciar los relés de modo conmutado asegurando aislamiento de transitorios.
* **Actividades técnicas:**
  1. Desarrollo del driver de bajo nivel para el convertidor ADC HX711 (pines `DOUT` y `PD_SCK`), generando 24 pulsos de reloj para captura del valor en complemento a dos, más 1 pulso adicional para programar Ganancia 128 en el Canal A.
  2. Implementación de una rutina de filtrado digital no bloqueante (descarte de las dos primeras muestras post-conmutación y cálculo de mediana móvil sobre 5 muestras consecutivas) para eliminar ruido impulsivo.
  3. Programación del secuenciador de salidas digitales en el ESP32 para el control de los transistores que conmutan el banco de relés K1..K5.
  4. Implementación estricta de retardos de guarda (*dead-time* / *settling time* de 20 ms) entre la apertura/cierre de los relés y el inicio del tren de pulsos del ADC para garantizar estabilidad de contactos mecánicos.
  5. Calibración experimental de escala utilizando una caja de décadas de resistencias patrón de $350\,\Omega$ y $120\,\Omega$ simulando desbalances conocidos de galgas ($\pm 500\,\mu\varepsilon$ a $\pm 3000\,\mu\varepsilon$).
* **Checkpoints medibles para revisión:**
  - [ ] **CP 4.1:** Driver de lectura del HX711 operativo con tiempo de lectura determinista; dispersión de ruido en reposo inferior a $\pm 5$ cuentas LSB con resistencia patrón fija.
  - [ ] **CP 4.2:** Formas de onda del accionamiento de relés y la línea de reloj del ADC capturadas en osciloscopio, evidenciando un tiempo muerto limpio de 20 ms sin solapamiento de contactos.
  - [ ] **CP 4.3:** Curva de calibración estática (cuentas ADC vs desbalance en microvoltios) con coeficiente de correlación $R^2 \ge 0.999$.

---

### Fase 5: Datalogger MicroSD, Interfaz LCD y Protocolo Externo RS-232 / SCADA
* **Duración:** 24 horas (Semanas 7–8)
* **Objetivo:** Implementar la persistencia local de datos en memoria flash, la interfaz visual alfanumérica y el protocolo de telemetría por comandos ASCII para sistemas SCADA.
* **Actividades técnicas:**
  1. Configuración del bus SPI en el ESP32 para el módulo de memoria MicroSD, montando el sistema de archivos FAT32 mediante la librería `SD` o `SdFat`.
  2. Creación estructurada del archivo de datos `DATALOG.CSV` con cabecera estandarizada:
     `TIMESTAMP,FECHA,HORA,CANAL,MODO,RAW_ADC,VALOR_ING,ESTADO`
     con volcado forzado al medio físico (*flush*) tras cada registro para prevenir pérdida ante cortes imprevistos de energía.
  3. Integración de la pantalla LCD alfanumérica (vía bus paralelo o interfaz I2C), mostrando el estado del sistema: versión de firmware, canal en barrido actual, lectura en $\mu\varepsilon$ y temperatura ($^\circ\text{C}$).
  4. Desarrollo del intérprete de comandos ASCII externos por el puerto serie principal (RS-232 a 115200 bps):
     * `READ:CH <1..24>`: Conmuta motor, relés y retorna deformación y temperatura.
     * `SCAN:ALL`: Inicia el barrido secuencial de los 24 canales.
     * `CAL:ZERO`: Registra la tara eléctrica para el canal activo.
     * `LOG:STATUS`: Entrega espacio en SD y número de registros almacenados.
* **Checkpoints medibles para revisión:**
  - [ ] **CP 5.1:** Archivo `DATALOG.CSV` generado y legible de forma nativa en PC tras retirar la tarjeta SD sin corrupciones de sectores ni caracteres extraños.
  - [ ] **CP 5.2:** Pantalla LCD actualizando en tiempo real la información de canal y mediciones con refresco estable sin parpadeos.
  - [ ] **CP 5.3:** Intérprete RS-232 respondiendo con tramas válidas terminadas en `\r\n` a todos los comandos definidos en menos de 100 ms tras completar la acción.

---

### Fase 6: Barrido Secuencial Completo de 24 Canales y Validación Experimental en Banco
* **Duración:** 18 horas (Semanas 9–10)
* **Objetivo:** Orquestar el funcionamiento integrado de los dos microcontroladores en un ciclo completo de auscultación sobre los 24 canales y evaluar la resiliencia del sistema ante fallos.
* **Actividades técnicas:**
  1. Implementación de la máquina de estados de barrido secuencial global:
     * Canales 1 al 12: Comandar movimiento escalonado a M1 mientras M2 permanece desenergizado.
     * Canales 13 al 24: Comandar movimiento escalonado a M2 mientras M1 permanece desenergizado.
  2. Integración de la secuencia de medición por canal: Posicionamiento motor $\rightarrow$ confirmación PIC $\rightarrow$ activación K1..K5 Deformación $\rightarrow$ muestreo HX711 $\rightarrow$ activación K1..K5 Temperatura $\rightarrow$ muestreo HX711 $\rightarrow$ almacenamiento en SD $\rightarrow$ emisión RS-232.
  3. Optimización del tiempo total de barrido para completar los 24 sensores en una ventana temporal inferior a 90 segundos.
  4. Ensayos de tolerancia a fallos: simular atasco forzado en uno de los motores o desconexión del cable UART, verificando que el ESP32 registre el error (`ERROR_M_STALL`) en el archivo CSV y continúe el escaneo con el segundo selector sin colgarse.
  5. Ensayo continuo prolongado de 100 barridos consecutivos en banco de laboratorio con banco de resistencias patrón.
* **Checkpoints medibles para revisión:**
  - [ ] **CP 6.1:** Barrido de los 24 canales completado de forma 100% autónoma en menos de 90 segundos por ciclo.
  - [ ] **CP 6.2:** Dataset continuo de 100 barridos (2400 mediciones) registrado en MicroSD sin pérdida de registros ni incongruencias en los números de canal.
  - [ ] **CP 6.3:** Comprobación de resiliencia: el sistema detecta atascos forzados, escribe el código de falla correspondiente y recupera la operación en el siguiente canal libre.

---

### Fase 7: Guía de Troubleshooting, Documentación Técnica e Informe Final
* **Duración:** 12 horas (Semanas 10–11)
* **Objetivo:** Consolidar la documentación formal de ingeniería, manual de servicio y redacción del Informe Técnico Final institucional.
* **Actividades técnicas:**
  1. Elaboración de la Guía de Solución de Problemas (*Troubleshooting*) detallando calibración de optoacopladores, ajuste de tensión en correas/engranajes de motores, resolución de atascos y fallas de bus UART.
  2. Compilación de evidencias experimentales: oscilogramas de frenado dinámico, curvas de linealidad del HX711, capturas de pantalla de la interfaz LCD y tablas de consumo energético.
  3. Redacción del Informe Técnico Final en formato institucional de la RSA y la Universidad de Cuenca, compilando la arquitectura de hardware/firmware, resultados y recomendaciones operativas para despliegue en presa.
  4. Revisión técnica con el tutor institucional, integración de retroalimentación y entrega del repositorio de código fuente ordenado y comentado.
* **Checkpoints medibles para revisión:**
  - [ ] **CP 7.1:** Borrador completo del Informe Técnico Final y Guía de Troubleshooting entregados para revisión de tutoría.
  - [ ] **CP 7.2:** Repositorio en GitHub estructurado con código fuente modular (carpetas `/pic_firmware` y `/esp32_firmware`), diagramas de cableado y archivo README descriptivo.
  - [ ] **CP 7.3:** Aprobación definitiva del informe y firma de actas de culminación de prácticas laborales.

---

## 4. Resumen de Fases y Cronograma Semanal (144 Horas)

El plan de trabajo comprende **144 horas** distribuidas en bloques semanales de **14 horas** (a lo largo de **10.5 semanas**) para un seguimiento exhaustivo de avances mediante checkpoints cuantitativos:

| Fase | Semanas | Horas | Enfoque Principal |
| :---: | :---: | :---: | :--- |
| **Fase 1** | Semana 1 | **15 h** | Diagnóstico de hardware, verificación eléctrica y caracterización de encoders en osciloscopio. |
| **Fase 2** | Semanas 2–3 | **30 h** | Firmware PIC: Homing absoluto, conteo de ranuras por interrupciones y frenado dinámico L293D. |
| **Fase 3** | Semana 4 | **15 h** | Protocolo serie binario robusto ESP32-PIC a 9600 bps con checksum XOR y máquina de reintentos. |
| **Fase 4** | Semanas 5–6 | **30 h** | Driver HX711 (24 bits), secuenciamiento de relés K1..K5 con tiempos muertos y calibración estática. |
| **Fase 5** | Semanas 7–8 | **24 h** | Datalogger en MicroSD (FAT32/CSV), menú informativo en LCD y comandos ASCII por RS-232 / SCADA. |
| **Fase 6** | Semanas 9–10 | **18 h** | Barrido automático completo de 24 canales ($\le 90\text{ s}$), tolerancia a atascos y prueba de 100 ciclos. |
| **Fase 7** | Semanas 10–11 | **12 h** | Guía de *troubleshooting*, consolidación de anexos, repositorio y redacción del Informe Final. |
| **Total** | **~10.5 Semanas** | **144 h** | **Planificación Global de Prácticas Preprofesionales** |

---

## 5. Entregables y Criterios de Éxito de la Pasantía

1. **Firmware del Controlador Esclavo (PIC16F628A):**
   * Código fuente en C (MPLAB X / XC8) modular y comentado, implementando máquinas de estado de *Homing*, conteo de ranuras por interrupciones y frenado dinámico de motor.
   * Parser receptor binario UART con validación de checksum XOR y reporte determinista de estados y alertas de atasco.
2. **Firmware del Nodo Maestro de Adquisición (ESP32):**
   * Código fuente en C++ (PlatformIO / Arduino Core o ESP-IDF) con arquitectura multihilo/modular.
   * Controlador de bajo nivel para el convertidor analógico-digital HX711 con filtrado de mediana móvil.
   * Secuenciador con tiempos muertos de relés K1..K5 para alternancia entre modo Deformación y Temperatura.
   * Datalogger en MicroSD en formato CSV plano legible sin dependencia de software propietario.
   * Interfaz gráfica local en LCD y controlador serie RS-232 compatible con comandos SCADA ASCII estándar.
3. **Paquete de Evidencia y Validación Experimental:**
   * Reporte fotográfico y capturas de osciloscopio demostrando la ausencia de sobreimpulsos en los discos selectores tras aplicar frenado dinámico.
   * Gráficas de dispersión y linealidad del HX711 demostrando estabilidad de lectura ($\sigma < 5\text{ LSB}$) en resistencias patrón.
   * Dataset de validación de 100 barridos continuos de 24 canales (2400 registros) verificando integridad y coherencia temporal.
4. **Guía de Troubleshooting y Manual de Operación:**
   * Documento técnico paso a paso para diagnóstico de averías mecánicas, desajustes ópticos, sustitución de transistores o relés y configuración de parámetros en campo.
5. **Informe Técnico Final Institucional:**
   * Documento formal compilado en formato institucional RSA / Universidad de Cuenca que consolida antecedentes, diseño circuital, diagramas de flujo de firmware, resultados experimentales y conclusiones.

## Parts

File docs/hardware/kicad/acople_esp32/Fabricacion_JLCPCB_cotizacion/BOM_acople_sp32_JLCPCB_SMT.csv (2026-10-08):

Comment | Designator | Footprint | LCSC Part # | Type
10uF 25V X5R | C1, C4, C6, C8, C12 | C_0805_2012Metric | C15850 | Basic Part / Extended
22uF 16V X5R | C2 | C_0805_2012Metric | C44026 | Extended Part
0.1uF 50V X7R | C3, C5, C7, C9, C10, C11, C13, C14 | C_0805_2012Metric | C49678 | Basic Part
600R@100MHz 2A | FB1 | L_0805_2012Metric | C1015 | Basic Part
S8550 PNP (2TY) | Q1 | SOT-23 | C2146 | Basic Part
20k 1% | R1 | R_0805_2012Metric | C26002 | Extended Part
8.2k 1% | R2 | R_0805_2012Metric | C26081 | Extended Part
100R 1% | R4, R5 | R_0805_2012Metric | C17462 | Basic Part
10k 1% | R6 | R_0805_2012Metric | C17414 | Basic Part
1k 1% | R7 | R_0805_2012Metric | C17513 | Basic Part
2k 1% | R8 | R_0805_2012Metric | C17538 | Extended Part
ESP32-WROOM-32U-N4 | U1 | ESP32-WROOM-32U | C328062 | Extended Part
HX711 24-bit ADC | U2 | SOIC-16_3.9x9.9mm_P1.27mm | C43656 | Extended Part
AMS1117-3.3 | U3 | SOT-223-3_TabPin2 | C6186 | Basic Part
CJ78M05 5V 500mA | U4 | TO-252-3_TabPin2 | C9070 | Extended Part

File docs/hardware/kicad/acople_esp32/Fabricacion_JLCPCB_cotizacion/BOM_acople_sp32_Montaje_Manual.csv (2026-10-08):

Designator | Value | Footprint | Description | LCSC Part #
J10 | Acondicionamiento 2 | PinHeader_1x05_P2.54mm_Vertical | Tira de pines macho 1x05 paso 2.54 mm vertical | C49257
J2 | Acondicionamiento 1 | PinHeader_2x05_P2.54mm_Vertical | Tira de pines macho 2x05 paso 2.54 mm vertical | C22554
J4 | Fuente 1 | PinHeader_1x06_P2.54mm_Vertical | Tira de pines macho 1x06 paso 2.54 mm vertical | C22551
J5 | Fuente 2 | PinHeader_1x08_P2.54mm_Vertical | Tira de pines macho 1x08 paso 2.54 mm vertical | C22553
J_DIP40 | CONECTOR_DIP40_MACHO | DIP-40_W15.24mm | Conector / tira macho formato DIP-40 paso 2.54 mm ancho 15.24 mm | C37207
J_PROG1 | PROGRAMADOR_RSA | PinHeader_1x06_P2.54mm_Vertical | Tira de pines macho 1x06 paso 2.54 mm vertical para pogo pins o programación | C22551

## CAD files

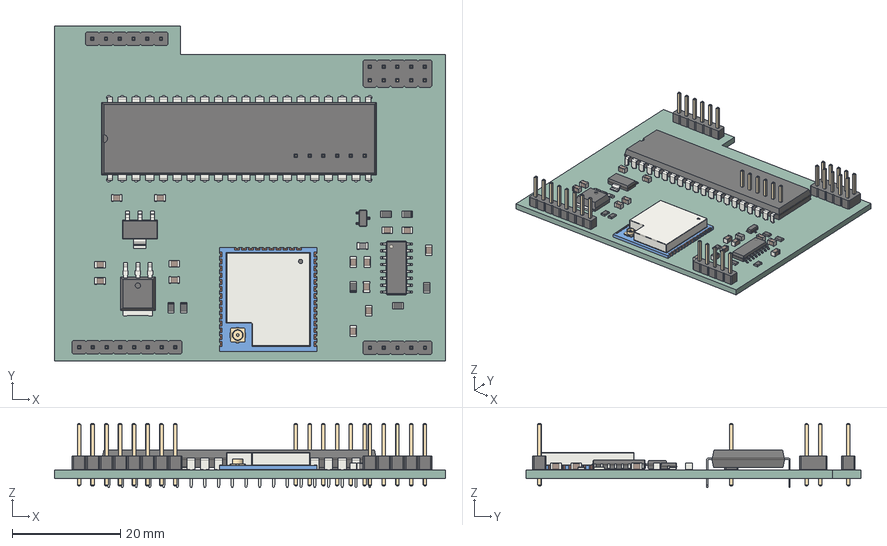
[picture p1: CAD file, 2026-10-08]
docs/hardware/kicad/acople_esp32/Fabricacion_JLCPCB_cotizacion/acople_sp32_ensamble_3D.step
72.3 x 62.0 x 11.8 mm
C_0805_2012Metric x 14
DIP-40_W15.24mm
R_0805_2012Metric x 7
PinHeader_1x06_P254mm_Vertical x 2
PinHeader_1x08_P254mm_Vertical
PinHeader_2x05_P254mm_Vertical
SOIC-16_3.9x9.9mm_P1.27mm
SOT-23
98f8d7e1-9c39-11ed-93f0-dde97e994e83_part
98f8d7e2-9c39-11ed-93f0-dde97e994e83_part
98f8d7e3-9c39-11ed-93f0-dde97e994e83_part
L_0805_2012Metric
ESP32-WROOM-32U
PinHeader_1x05_P254mm_Vertical
SOT-223
acople_sp32_PCB

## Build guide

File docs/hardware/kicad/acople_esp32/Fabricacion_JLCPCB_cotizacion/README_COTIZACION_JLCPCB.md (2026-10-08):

# Guía de Cotización y Fabricación JLCPCB: Acople Cajas de Revisión (`acople_sp32`)

Este directorio contiene el paquete integral para la cotización y fabricación rápida en **JLCPCB** (PCB + Ensamble SMT).

---

## 📦 Contenido del Paquete

1. **`acople_sp32_gerbers.zip`**: Archivo comprimido con todos los planos Gerbers RS-274X y archivos de taladro Excellon (PTH y NPTH). Listo para arrastrar y soltar en [jlcpcb.com/quote](https://jlcpcb.com/quote).
2. **`BOM_acople_sp32_JLCPCB_SMT.csv`**: Lista de materiales SMD con códigos de catálogo LCSC verificados para cotización y compra automática de piezas.
3. **`CPL_acople_sp32_JLCPCB.csv`**: Archivo de centroides Pick & Place con coordenadas milimétricas y capas para el robot SMT.
4. **`BOM_acople_sp32_Montaje_Manual.csv`**: Lista de conectores THT y tiras de pines para soldadura manual en laboratorio o taller.
5. **`acople_sp32_ensamble_3D.step`**: Modelo 3D electromecánico completo (PCB + componentes) para validación de carcasas y gabinetes.

---

## 🛠️ Parámetros Técnicos para el Cotizador de JLCPCB

Al cargar `acople_sp32_gerbers.zip`, el sistema detectará automáticamente los parámetros básicos. Verifica los siguientes datos:

| Parámetro | Valor Recomendado | Notas |
| :--- | :--- | :--- |
| **Dimensiones** | **72.31 mm × 62.01 mm** | Detectado automáticamente por Gerber |
| **Capas (Layers)** | **2 Layers** | Capas Top y Bottom |
| **Material** | **FR-4 Standard** | TG 130-140 o TG 150 |
| **Espesor de Placa** | **1.6 mm** | Estándar recomendado |
| **Color de Máscara (Solder Mask)** | **Green** (o a elección) | Verde es el más económico y rápido |
| **Color de Serigrafía (Silkscreen)** | **White** | Contraste óptimo con logos RSA |
| **Acabado Superficial** | **HASL lead-free** o **ENIG** | HASL sin plomo (económico) o ENIG (dorado plano de alta durabilidad) |
| **Peso de Cobre** | **1 oz** (35 µm) | Estándar para señales y alimentación |
| **Confirmación de Borde** | No panelizar (Single PCB) | Placa individual con corte perimetral limpio |

---

## 🤖 Parámetros para Ensamble SMT (PCB Assembly)

Activa la opción **"PCB Assembly"** en la parte inferior del cotizador:

- **Assembly Side**: **Top Side Only** (¡Todos los 27 componentes SMD están en la cara superior, ahorrando costo de doble cara!).
- **PCBA Quantity**: Selecciona cuántas unidades deseas ensambladas (ej. 2, 5 o 10).
- **Tooling Holes**: "Added by JLCPCB" (ellos añaden borde de descarte para los rieles de montaje).
- **Confirmación de Partes**: Al cargar `BOM_acople_sp32_JLCPCB_SMT.csv` y `CPL_acople_sp32_JLCPCB.csv`, la herramienta de JLCPCB previsualizará en 3D la posición de cada integrado, resistencia y condensador. Si la orientación de algún transistor o integrado requiere ajuste de 90° o 180°, la interfaz web de JLCPCB dispone de un botón de rotación gráfica de un solo clic antes de confirmar el pedido.

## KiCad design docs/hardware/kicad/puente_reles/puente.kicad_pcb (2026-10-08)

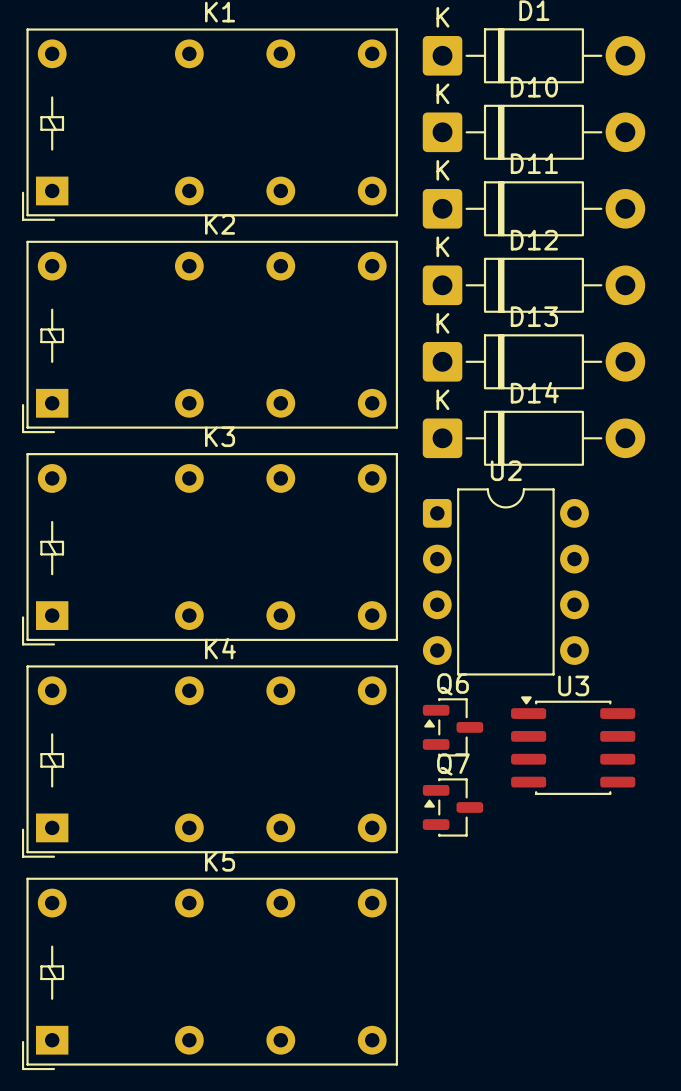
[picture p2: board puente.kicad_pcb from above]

Board: 2 copper layers, 15 parts (0 on the bottom side), 14 nets, no tracks yet.

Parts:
D1, D10, D11, D12, D13, D14: 1N4007; D_DO-41_SOD81_P10.16mm_Horizontal
K1, K2, K3, K4, K5: HK19F-DCxxV-SHC; Relay_DPDT_Finder_30.22
Q6, Q7: BSS138; SOT-23
U2: DS1307+; DIP-8_W7.62mm
U3: MAX483E; SOIC-8_3.9x4.9mm_P1.27mm

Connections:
/+5V: U2.8 (VCC), U3.8 (VCC)
/+12V: D10.1 (K), D11.1 (K), D12.1 (K), D13.1 (K), D14.1 (K), K1.A1, K2.A1, K3.A1, K4.A1, K5.A1
/IN-: K4.12, K4.24
GND: U2.4 (GND), U3.5 (GND)
unnamed: D10.2 (A), K1.A2
unnamed: D11.2 (A), K2.A2
unnamed: D12.2 (A), K3.A2
unnamed: D13.2 (A), K4.A2
unnamed: D14.2 (A), K5.A2
unnamed: K2.24, K4.22
unnamed: K3.14, K5.11
unnamed: Q6.3 (D), U2.5 (SDA)
unnamed: Q7.3 (D), U2.6 (SCL)
VDD: D1.2 (A), K2.21, Q6.1 (G), Q7.1 (G)

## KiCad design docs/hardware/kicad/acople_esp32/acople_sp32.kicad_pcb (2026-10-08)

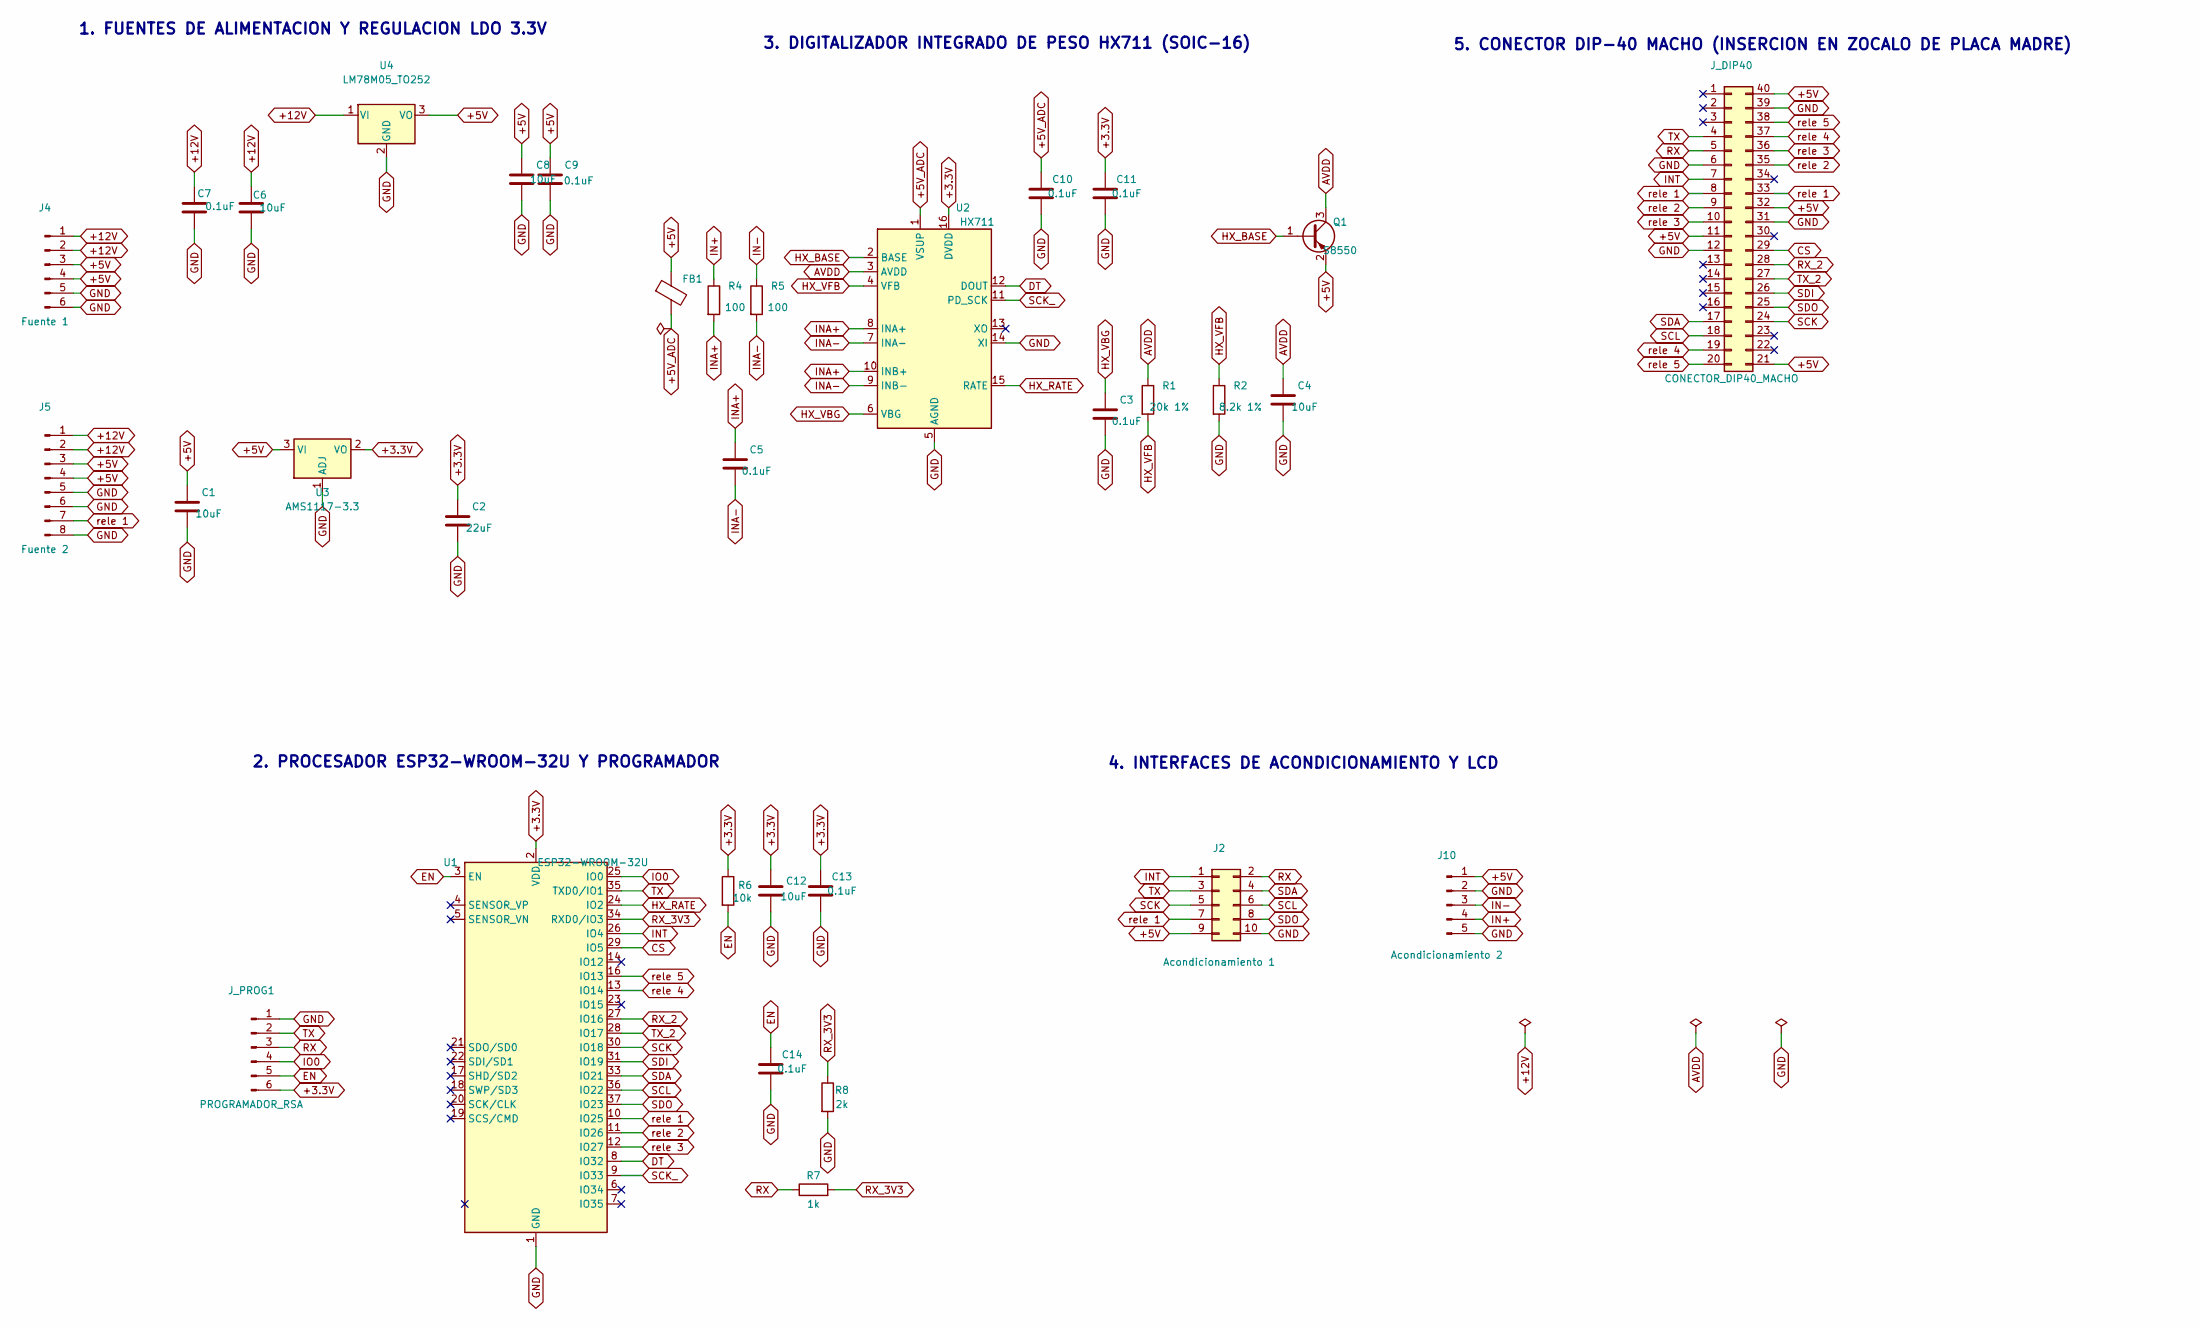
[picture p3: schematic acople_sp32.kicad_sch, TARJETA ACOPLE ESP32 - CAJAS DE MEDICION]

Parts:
C1, C4, C6, C8, C12: 10uF; C_0805_2012Metric
C2: 22uF; C_0805_2012Metric
C3, C5, C7, C9, C10, C11, C13, C14: 0.1uF; C_0805_2012Metric
FB1: 600R@100MHz; L_0805_2012Metric
J2: Acondicionamiento 1; PinHeader_2x05_P2.54mm_Vertical
J4: Fuente 1; PinHeader_1x06_P2.54mm_Vertical
J5: Fuente 2; PinHeader_1x08_P2.54mm_Vertical
J10: Acondicionamiento 2; PinHeader_1x05_P2.54mm_Vertical
J_DIP40: CONECTOR_DIP40_MACHO; DIP-40_W15.24mm
J_PROG1: PROGRAMADOR_RSA; PinHeader_1x06_P2.54mm_Vertical
Q1: S8550; SOT-23
R1: 20k 1%; R_0805_2012Metric
R2: 8.2k 1%; R_0805_2012Metric
R4, R5: 100; R_0805_2012Metric
R6: 10k; R_0805_2012Metric
R7: 1k; R_0805_2012Metric
R8: 2k; R_0805_2012Metric
U1: ESP32-WROOM-32U
U2: HX711; SOIC-16_3.9x9.9mm_P1.27mm
U3: AMS1117-3.3; SOT-223-3_TabPin2
U4: LM78M05_TO252; TO-252-3_TabPin2

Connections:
+3.3V: C2.1, C11.1, C12.1, C13.1, J_PROG1.6, R6.1, U1.2 (VDD), U2.16 (DVDD), U3.2 (VO)
+5V: C1.1, C8.1, C9.1, FB1.1, J2.9, J4.3, J4.4, J5.3, J5.4, J10.1, J_DIP40.11, J_DIP40.21, J_DIP40.32, J_DIP40.40, Q1.2 (E), U3.3 (VI), U4.3 (VO)
+5V_ADC: C10.1, FB1.2, U2.1 (VSUP)
+12V: C6.1, C7.1, J4.1, J4.2, J5.1, J5.2, U4.1 (VI)
AVDD: C4.1, Q1.3 (C), R1.1, U2.3 (AVDD)
CS: J_DIP40.29, U1.29 (IO5)
DT: U1.8 (IO32), U2.12 (DOUT)
EN: C14.1, J_PROG1.5, R6.2, U1.3 (EN)
GND: C1.2, C2.2, C3.2, C4.2, C6.2, C7.2, C8.2, C9.2, C10.2, C11.2, C12.2, C13.2, C14.2, J2.10, J4.5, J4.6, J5.5, J5.6, J5.8, J10.2, J10.5, J_DIP40.6, J_DIP40.12, J_DIP40.31, J_DIP40.39, J_PROG1.1, R2.2, R8.2, U1.1 (GND), U1.15 (GND), U1.38 (GND), U1.39 (GND), U2.5 (AGND), U2.14 (XI), U3.1 (ADJ), U4.2 (GND)
HX_BASE: Q1.1 (B), U2.2 (BASE)
HX_RATE: U1.24 (IO2), U2.15 (RATE)
HX_VBG: C3.1, U2.6 (VBG)
HX_VFB: R1.2, R2.1, U2.4 (VFB)
IN+: J10.4, R4.1
IN-: J10.3, R5.1
INA+: C5.1, R4.2, U2.8 (INA+), U2.10 (INB+)
INA-: C5.2, R5.2, U2.7 (INA-), U2.9 (INB-)
INT: J2.1, J_DIP40.7, U1.26 (IO4)
IO0: J_PROG1.4, U1.25 (IO0)
RX: J2.2, J_DIP40.5, J_PROG1.3, R7.1
RX_2: J_DIP40.28, U1.27 (IO16)
RX_3V3: R7.2, R8.1, U1.34 (RXD0/IO3)
SCK: J2.5, J_DIP40.24, U1.30 (IO18)
SCK_: U1.9 (IO33), U2.11 (PD_SCK)
SCL: J2.6, J_DIP40.18, U1.36 (IO22)
SDA: J2.4, J_DIP40.17, U1.33 (IO21)
SDI: J_DIP40.26, U1.31 (IO19)
SDO: J2.8, J_DIP40.25, U1.37 (IO23)
TX: J2.3, J_DIP40.4, J_PROG1.2, U1.35 (TXD0/IO1)
TX_2: J_DIP40.27, U1.28 (IO17)
rele 1: J2.7, J5.7, J_DIP40.8, J_DIP40.33, U1.10 (IO25)
rele 2: J_DIP40.9, J_DIP40.35, U1.11 (IO26)
rele 3: J_DIP40.10, J_DIP40.36, U1.12 (IO27)
rele 4: J_DIP40.19, J_DIP40.37, U1.13 (IO14)
rele 5: J_DIP40.20, J_DIP40.38, U1.16 (IO13)

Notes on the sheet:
2. PROCESADOR ESP32-WROOM-32U Y PROGRAMADOR
1. FUENTES DE ALIMENTACION Y REGULACION LDO 3.3V
5. CONECTOR DIP-40 MACHO (INSERCION EN ZOCALO DE PLACA MADRE)
4. INTERFACES DE ACONDICIONAMIENTO Y LCD
3. DIGITALIZADOR INTEGRADO DE PESO HX711 (SOIC-16)

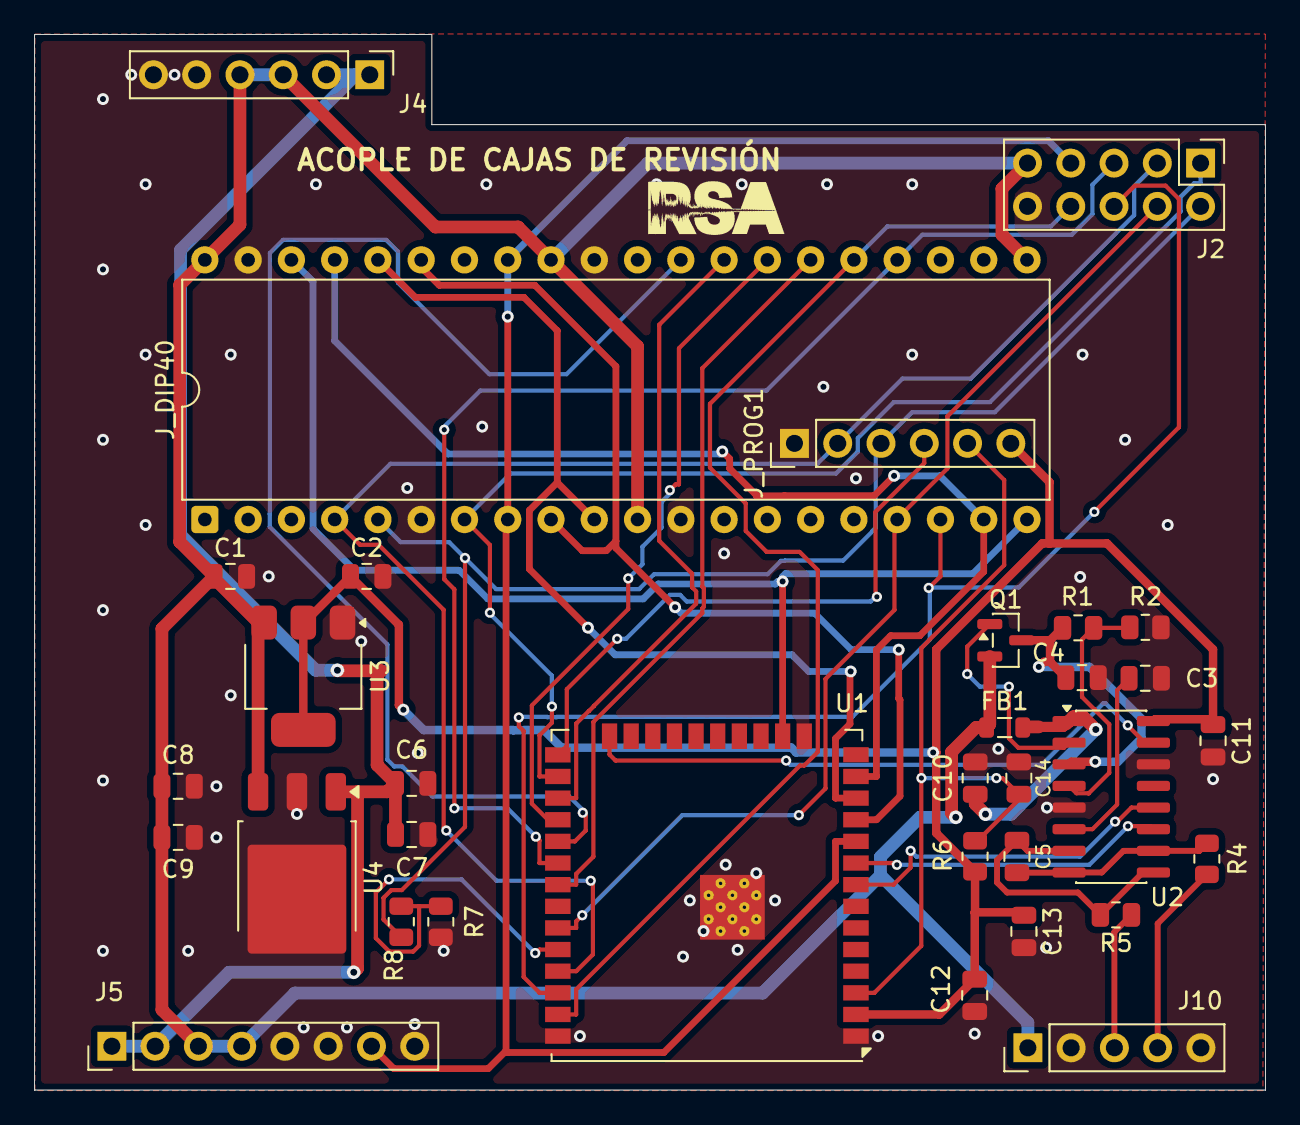
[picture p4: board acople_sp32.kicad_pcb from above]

Board: 2 copper layers, 72.3 x 62.0 mm, 35 parts (1 on the bottom side), 35 nets.

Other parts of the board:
LOGO_B: Logo_RSA; Logo_RSA_Grande
LOGO_F: Logo_RSA

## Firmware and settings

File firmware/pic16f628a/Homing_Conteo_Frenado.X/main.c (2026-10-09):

#include <xc.h>

#pragma config FOSC = INTOSCIO  
#pragma config WDTE = OFF       
#pragma config PWRTE = ON       
#pragma config MCLRE = OFF      
#pragma config BOREN = ON       
#pragma config LVP = OFF        
#pragma config CPD = OFF        
#pragma config CP = OFF         

#define _XTAL_FREQ 4000000      

// Pines L293D
#define DIR_A       PORTBbits.RB3   
#define DIR_B       PORTAbits.RA1   
#define ENABLE_M1   PORTBbits.RB5   

// Sensores
#define SENS1_M1    PORTAbits.RA2   // Encoder de Paso (Ranuras continuas)
#define SENS2_M1    PORTAbits.RA3   // Encoder Home (Muesca única)

int posicion_actual_m1 = 0;

void inicializar() {
    CMCON = 0x07;       
    TRISBbits.TRISB3 = 0; 
    TRISAbits.TRISA1 = 0; 
    TRISBbits.TRISB5 = 0; 
    TRISAbits.TRISA2 = 1; 
    TRISAbits.TRISA3 = 1; 
    ENABLE_M1 = 0; DIR_A = 0; DIR_B = 0;
}

void frenado_dinamico_m1() {
    DIR_A = 1;
    DIR_B = 1;      
    ENABLE_M1 = 1;  
    __delay_ms(50); // Frenado exacto
    
    ENABLE_M1 = 0;  
    DIR_A = 0;
    DIR_B = 0;
}

// ========================================================
// 1. HOMING 
// ========================================================
void probar_homing_lento_m1() {
    DIR_A = 1;
    DIR_B = 0;
    
    int pulsos_on = 10;   
    int pulsos_off = 30; 

    while(1) {
        ENABLE_M1 = 1;
        for(int i = 0; i < pulsos_on; i++) {
            if(SENS2_M1 == 0) { // Busca el 0V
                frenado_dinamico_m1();
                posicion_actual_m1 = 1;
                return;
            }
            __delay_us(100);
        }
        
        ENABLE_M1 = 0;
        for(int i = 0; i < pulsos_off; i++) {
            if(SENS2_M1 == 0) { 
                frenado_dinamico_m1();
                posicion_actual_m1 = 1;
                return;
            }
            __delay_us(100);
        }
    }
}

// ========================================================
// 2. CONTEO (Nuevo, alta velocidad buscando flanco de subida)
// ========================================================
// Actividad 2: Conteo por lógica pura de flancos (Sin retardos de tiempo)
void ir_a_posicion_m1(int posicion_destino) {
    int pasos_a_dar = posicion_destino - posicion_actual_m1;
    if(pasos_a_dar < 0) pasos_a_dar += 12; 
    if(pasos_a_dar == 0) return; 
    
    // 60 muescas / 12 posiciones = 5 muescas físicas por paso
    int ranuras_objetivo = pasos_a_dar * 5; 
    int ranuras_contadas = 0;
    
    int estado_anterior = SENS1_M1; 
    
    DIR_A = 0;
    DIR_B = 1;
    int pulsos_on = 10;   
    int pulsos_off = 31; 
    int ciclo_pwm = 0;

    while(1) { 
        // 1. GENERADOR DE VELOCIDAD LENTA (PWM)
        ciclo_pwm++;
        if (ciclo_pwm <= pulsos_on) ENABLE_M1 = 1;
        else if (ciclo_pwm <= (pulsos_on + pulsos_off)) ENABLE_M1 = 0;
        else ciclo_pwm = 0;

        // 2. LÓGICA DE FLANCOS PURA
        int lectura_actual = SENS1_M1;

        if (lectura_actual != estado_anterior) {
            
            if (lectura_actual == 1) {
                // FLANCO DE SUBIDA: El sensor chocó con el plástico.
                // Registramos que acabamos de entrar a una nueva muesca.
                ranuras_contadas++;
            } 
            else if (lectura_actual == 0) {
                // FLANCO DE BAJADA: El sensor acaba de caer al hueco.
                if (ranuras_contadas >= ranuras_objetivo) {
                    frenado_dinamico_m1(); // ¡Freno instantáneo en el hueco!
                    posicion_actual_m1 = posicion_destino;
                    return; 
                }
            }
            estado_anterior = lectura_actual; // Actualizamos la "foto" del sensor
        }

        // 3. SEGURO DE VIDA PARA EL HOME
        // Respetamos la muesca única: Si vamos a la posición 1 y el sensor 2 cae al hueco, frena.
        if (posicion_destino == 1 && SENS2_M1 == 0) {
            frenado_dinamico_m1();
            posicion_actual_m1 = 1;
            return;
        }

        // Pausa minúscula solo para que el PWM funcione y el PIC no se sature
        __delay_us(100);
    }
}

void main(void) {
    inicializar();
    __delay_ms(2000); 
    
    probar_homing_lento_m1(); 
    __delay_ms(2000);
    
    while(1) { 
        ir_a_posicion_m1(4);
        __delay_ms(3000); 
        
        ir_a_posicion_m1(8);
        __delay_ms(3000);
        
        ir_a_posicion_m1(1);
        __delay_ms(3000);
    }
}

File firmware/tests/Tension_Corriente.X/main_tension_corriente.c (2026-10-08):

//Programa que permite hacer funcionar los motores para medir sus voltajes y corrrientes en reposos y en uso

#include <xc.h>

#pragma config FOSC = INTOSCIO  
#pragma config WDTE = OFF       
#pragma config PWRTE = ON       
#pragma config MCLRE = OFF      
#pragma config BOREN = ON       
#pragma config LVP = OFF        
#pragma config CPD = OFF        
#pragma config CP = OFF         

#define _XTAL_FREQ 4000000      

// Definición exacta según etiquetas de red en el esquemático
#define DIR_M1      PORTBbits.RB3   // Pin 9  -> M1 (Entradas 1A y 3A del L293D)
#define DIR_M2      PORTAbits.RA1   // Pin 18 -> M2 (Entradas 2A y 4A del L293D)
#define ENABLE_M1   PORTBbits.RB5   // Pin 11 -> M1_EN (Pin 1 EN1,2 del L293D)
#define ENABLE_M2   PORTBbits.RB4   // Pin 10 -> M2_EN (Pin 9 EN3,4 del L293D)

void main(void) {
    CMCON = 0x07;       // Desactiva comparadores analógicos en PORTA
    
    // Configuración de direcciones de pines
    TRISBbits.TRISB3 = 0; // M1 salida
    TRISBbits.TRISB4 = 0; // M2_EN salida
    TRISBbits.TRISB5 = 0; // M1_EN salida
    TRISAbits.TRISA1 = 0; // M2 salida
    
    // Estado inicial: Todo apagado
    ENABLE_M1 = 0;
    ENABLE_M2 = 0;
    DIR_M1 = 0;
    DIR_M2 = 0;

    while(1) {
        // =====================================
        // 1. ESTADO DE REPOSO (10 segundos)
        // =====================================
        ENABLE_M1 = 0;
        ENABLE_M2 = 0;
        DIR_M1 = 0;
        DIR_M2 = 0;
        __delay_ms(10000);

        // ==========================================
        // 2. SOLO MOTOR 1 EN MOVIMIENTO (10 segundos)
        // ==========================================
        DIR_M1 = 1;         // 1A = 1
        DIR_M2 = 0;         // 2A = 0 (Giro en sentido directo)
        ENABLE_M1 = 1;      // Habilita M1
        ENABLE_M2 = 0;
        __delay_ms(10000);

        // Pausa breve
        ENABLE_M1 = 0;
        __delay_ms(1500);

        // ==========================================
        // 3. SOLO MOTOR 2 EN MOVIMIENTO (10 segundos)
        // ==========================================
        DIR_M1 = 1;         // 3A = 1
        DIR_M2 = 0;         // 4A = 0
        ENABLE_M1 = 0;
        ENABLE_M2 = 1;      // Habilita M2
        __delay_ms(10000);

        // Pausa breve
        ENABLE_M2 = 0;
        __delay_ms(1500);

        // ==========================================
        // 4. AMBOS MOTORES AL MISMO TIEMPO (10 segundos)
        // ==========================================
        DIR_M1 = 1;
        DIR_M2 = 0;
        ENABLE_M1 = 1;
        ENABLE_M2 = 1;
        __delay_ms(10000);
    }
}

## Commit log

2026-10-08 feat: inicializar estructura de repositorio, planificacion y documentacion base
2026-10-08 docs: incorporar material heredado de hardware, firmware base y guia de referencia tecnica
    [BOM_acople_sp32_JLCPCB_SMT.csv, BOM_acople_sp32_Montaje_Manual.csv, acondicionamiento.kicad_pcb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]
2026-10-08 docs:prueba de psuh
2026-10-08 test: [prueba de reloj del PIC16F628A]
2026-10-08 test: [prueba de potencia L293D, tensión y corriente]
2026-10-09 feat: agregar firmware Homing_Conteo_Frenado
